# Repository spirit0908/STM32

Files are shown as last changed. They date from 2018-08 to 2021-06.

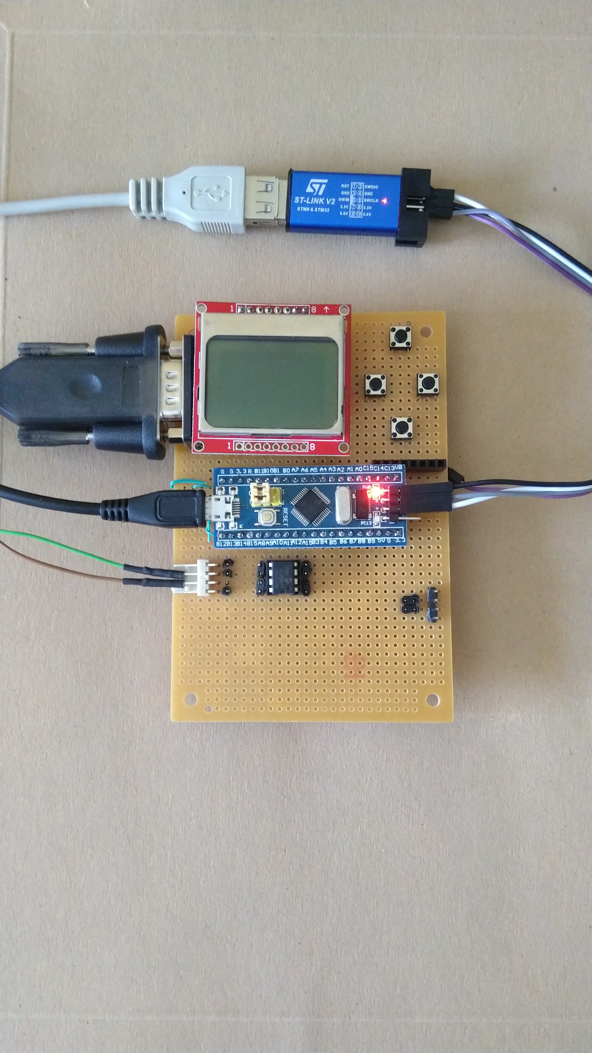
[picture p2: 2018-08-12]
PCB/STM32_proto_board.jpg

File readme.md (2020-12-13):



# Presentation of the project

## Modules
- Light management (dimmer, timer, LED strips...)
- Switch management
- Security Keypad
- Heat management

## Boards
- Development board (Proto board)
- Wall switch board
- Light control board
- Heater control board

## Architecture

Distributed network based on CAN bus

```
                        temp.                   wall
  I/O  I/O              sensor          light  switch
   |    |                 |               |       |
 +-+----+-----+     +-----+------+     +--+-------+-+
 |            |     |            |     |            |
 |  Module 1  |     |  Module 3  |     |  Moduel 5  |
 |            |     |            |     |            |
 +-----+------+     +-----+------+     +-----+------+ 
       |                  |                  |
       +-----+------------+-----+------------+-------- CAN Bus
             |                  |
       +-----+------+     +-----+------+ 
       |            |     |            |
       |  Module 2  |     |  Module 4  |
       |            |     |            |
       +-+-------+--+     +-----+------+
         |       |              |
       RFID   iButton      smart meter
      reader  reader        interface
```

## Boards

### Proto board
- LCD
- 4x switch
- 4x control output (RGBW)
- RS232
- CAN

### Relay board
- 4x switch
- 4x control output (RGBW)
- 6x relay output
- RS232
- CAN

### Intercom board
- 3x sensor input
- 2x relay output
- RS232
- CAN

# How to use

## How to compile

make

## How to execute the tests

make test

Test results location: out/tests/Test_report.html

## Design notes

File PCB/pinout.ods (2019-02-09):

Pin | Name | Port/Pin | Analog | Special function |  | PWM | Board
1 | +3.3V
2 | GND
3 | +5V
4 | PB9 | PB_9 | D14 | CAN1 TD | I2C1 SDA |  |  | PN532_SDA
5 | PB8 | PB_8 | D15 | CAN1 RD | I2C1 SCL |  |  | PN532_SCL
6 | PB7 | PB_7 |  | Serial1 RX | I2C1 SDA |  |  | FREE
7 | PB6 | PB_6 | D10 | Serial1 TX | I2C1 SCL |  |  | FREE
8 | PB5 | PB_5 | D4 | SPI1 MOSI |  | PWM3/2 | CAN_RS
9 | PB4 | PB_4 | D5 | SPI1 MISO |  | PWM3/1 |  | FREE
10 | PB3 | PB_3 | D3 | SPI1 SCK |  | PWM2/2 | LCD_CLK
11 | PA15 | PA_15 |  | SPI1 NSS |  | PWM2/1 |  | FREE
12 | PA12 | PA_12 | USB DP | CAN1 TD |  |  | CAN_TX
13 | PA11 | PA_11 | USB DM | CAN1 RD |  | PWM1/4 | CAN_RX
14 | PA10 | PA_10 | D2 | Serial1 TX |  | PWM1/3 |  | LED_STRIP | TIM3
15 | PA9 | PA_9 | D8 | Serial1 RX |  | PWM1/2 |  | LED_STRIP | TIM3
16 | PA8 | PA_8 | D7 |  |  | PWM1/1 |  | LED_STRIP | TIM3
17 | PB15 | PB_15 |  | SPI2 MOSI |  | PWM1/2N | LCD_DIN
18 | PB14 | PB_14 |  | SPI2 MISO |  | PWM1/2N | LCD_DC
19 | PB13 | PB_13 |  | SPI2 SCK |  | PWM1/1N | LCD_CE
20 | PB12 | PB_12 |  | SPI2 NSS |  |  | LCD_RST
21 | VSS
22 | VSS
23 | +3.3V
24 | RESET
25 | PB11 |  |  | Serial3 RX | I2C2 SDA |  | Teleinfo_EDF
26 | PB10 | PB_10 | D6 | Serial3 TX | I2C2 SCL |  | ND
27 | PB1 | PB_1 |  |  | Analog In |  |  | FREE
28 | PB0 | PB_0 | A3 |  | Analog In | PWM3/3 | LED_STRIP_R
29 | PA7 | PA_7 | D11 | SPI1 MOSI | Analog In | PWM3/2 | LED_STRIP_G
30 | PA6 | PA_6 | D12 | SPI1 MISO | Analog In | PWM3/1 | LED_STRIP_B
31 | PA5 | PA_5 | D13 | SPI1 SCK | Analog In |  |  | Relay2
32 | PA4 | PA_4 | A2 | SPI1 NSS | Analog In |  |  | Relay1
33 | PA3 | PA_3 | D0 | Serial2 RX | Analog In | PWM2/4 | Serial DBG RX
34 | PA2 | PA_2 | D1 | Serial2 TX | Analog In | PWM2/3 | Serial DBG TX
35 | PA1 | PA_1 | A1 |  | Analog In | PWM2/2 | PB_RIGHT
36 | PA0 | PA_0 | A0 |  | Analog In |  | PB_UP
37 | PC15 | PC_15 |  |  |  |  | PB_LEFT
38 | PC14 | PC_14 |  |  |  |  | PB_DOWN
39 | PC13 | PC_13 | C13 |  |  |  | LED
40 | VBAT

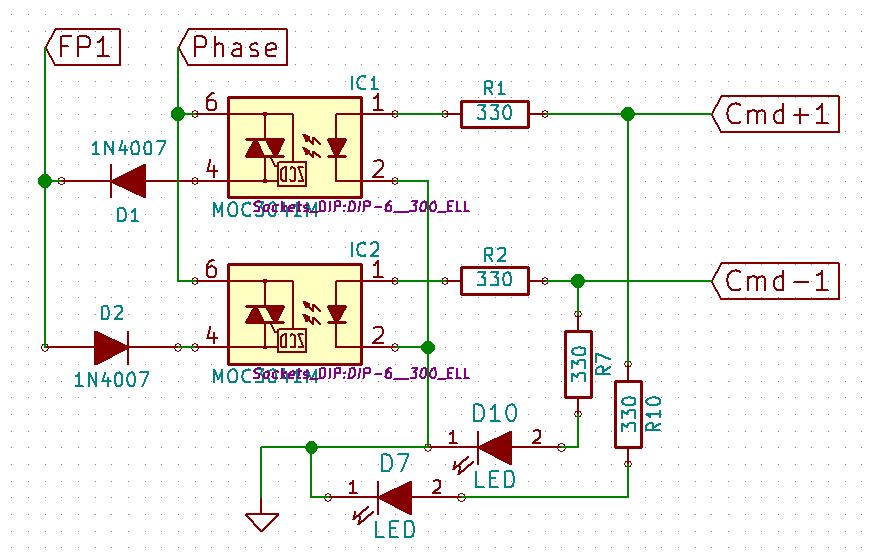
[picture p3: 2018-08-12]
modules/FilPilote/FilPilote_sch.jpg

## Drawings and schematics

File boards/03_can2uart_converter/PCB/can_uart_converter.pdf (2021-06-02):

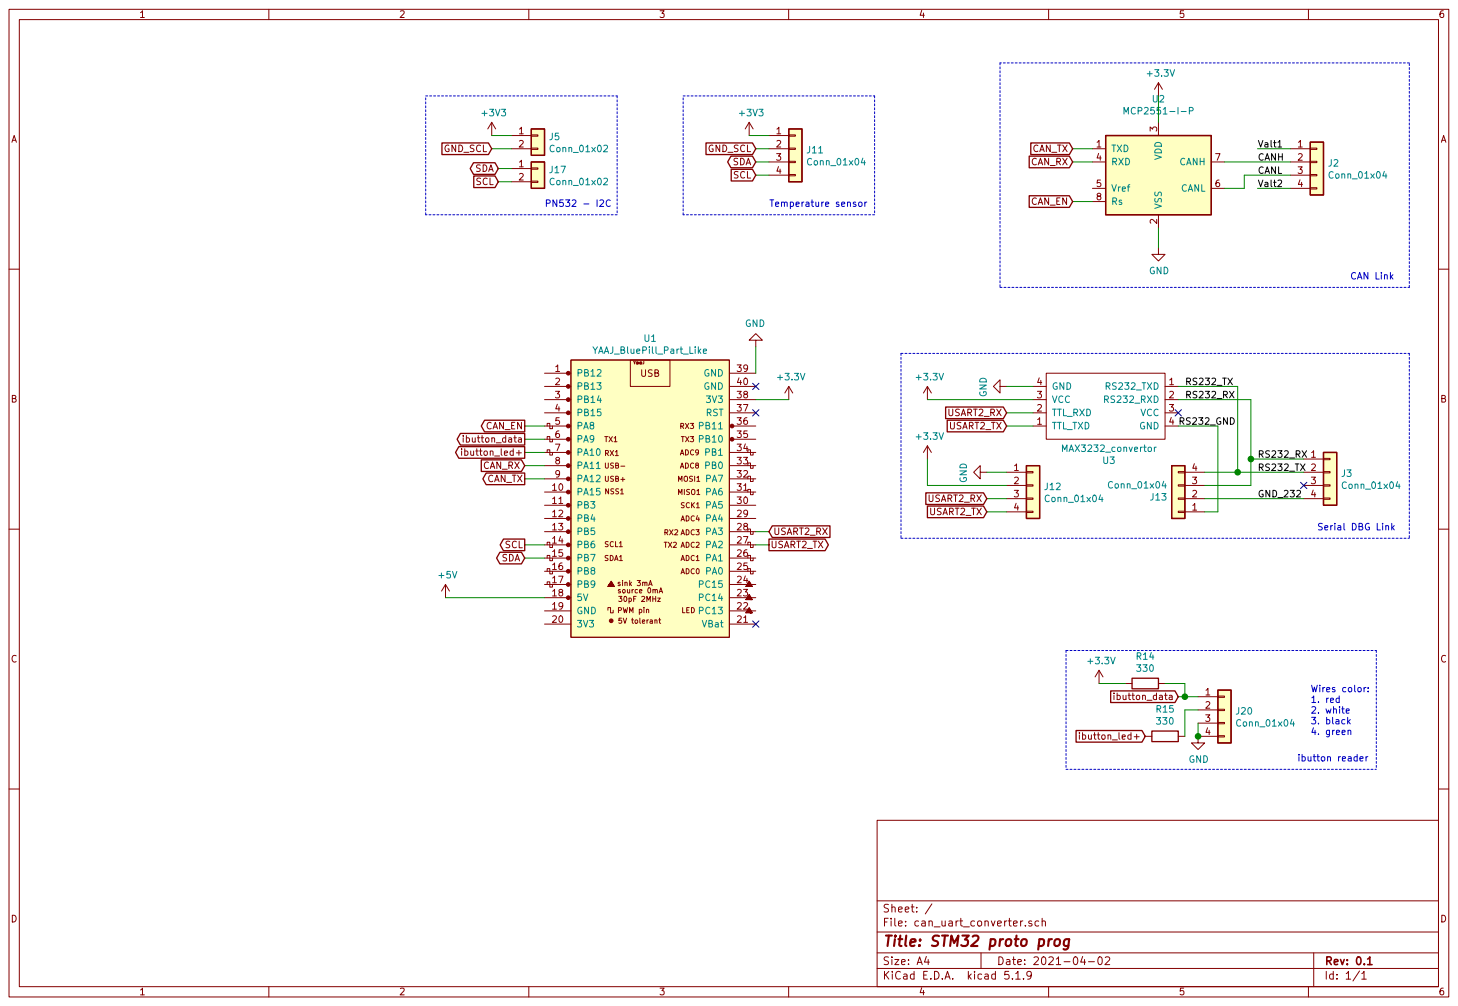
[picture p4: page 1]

3 RXD 4 Vref 5 CANL 6 CANH 7 Rs 8 U2 +3V3 MCP2551-I-P RS232_TXD 1 TTL_TXD 1 RS232_RXD 2 TTL_RXD 2 VCC 3 VCC 3 GND 4 GND 4 U3 MAX3232_convertor 1

File: can_uart_converter.sch Sheet: /
Id: 1/1 Title: STM32 proto prog

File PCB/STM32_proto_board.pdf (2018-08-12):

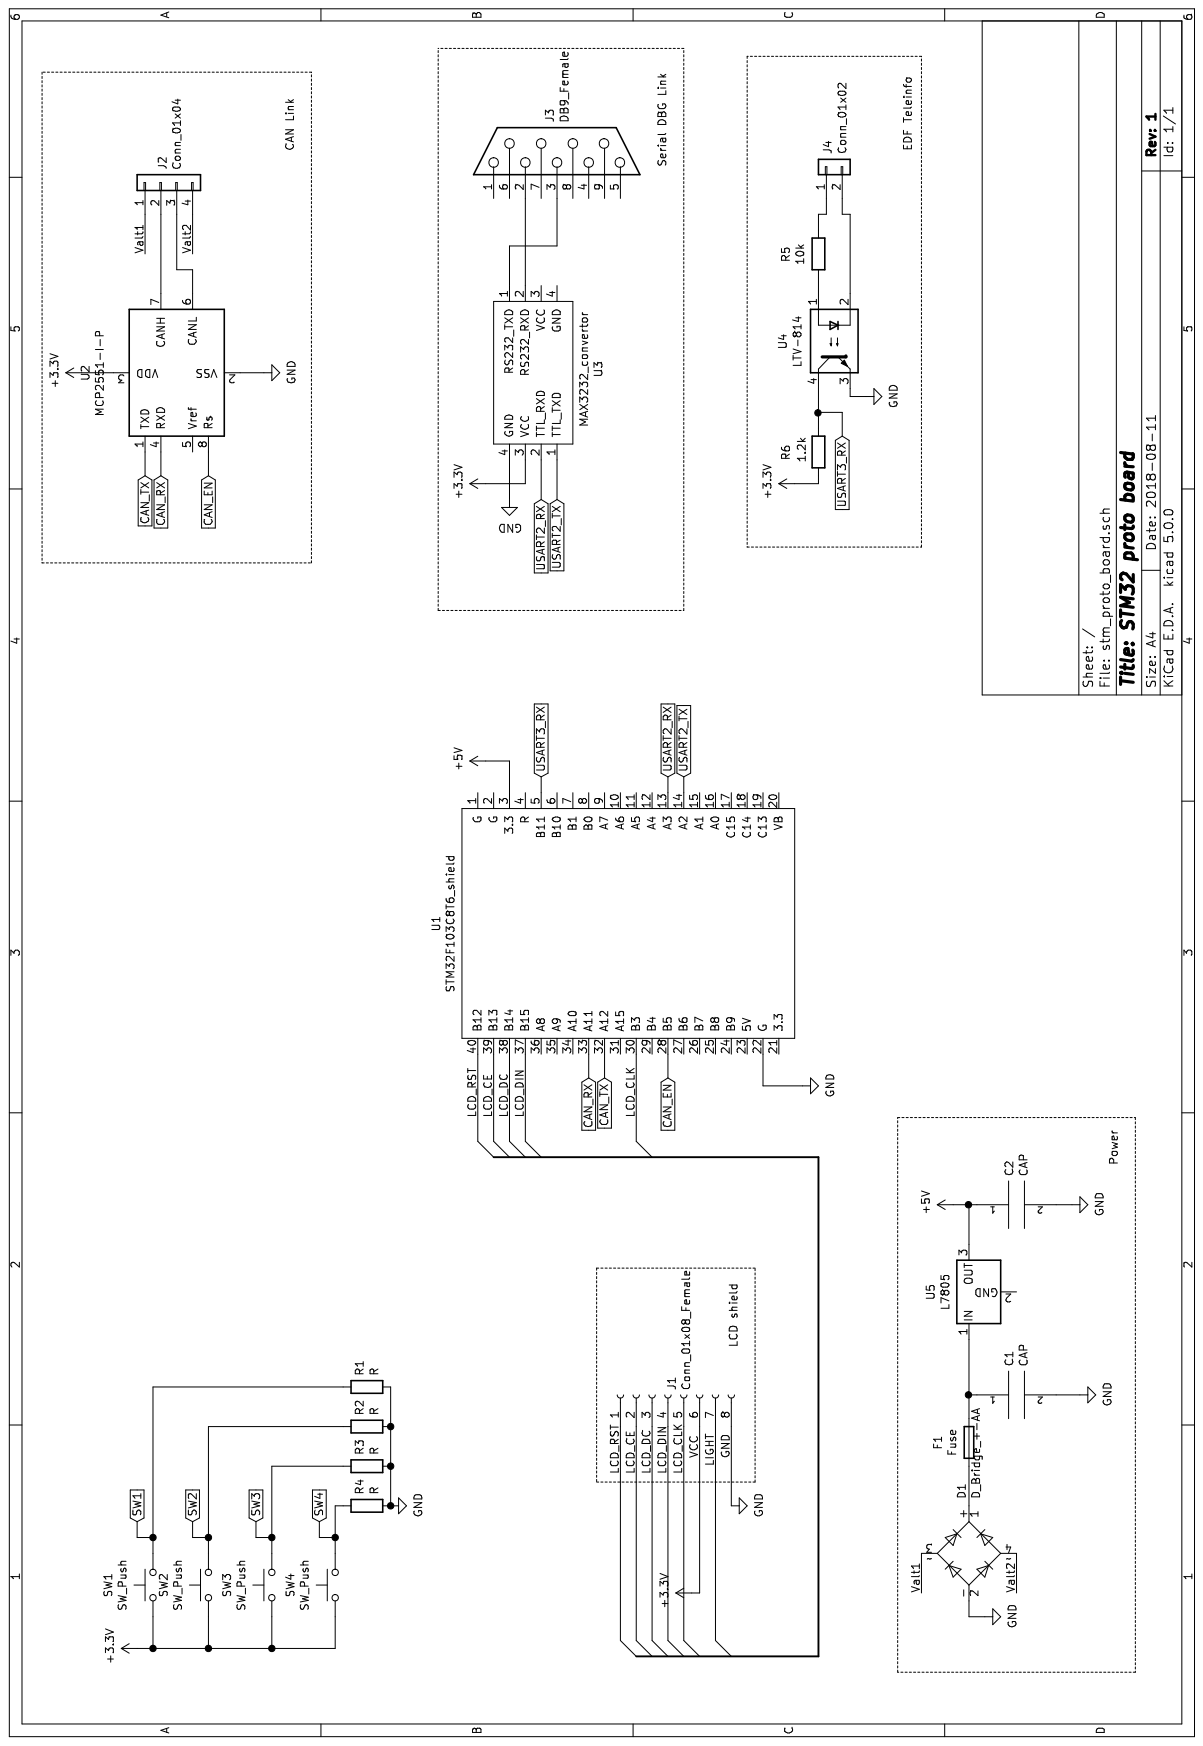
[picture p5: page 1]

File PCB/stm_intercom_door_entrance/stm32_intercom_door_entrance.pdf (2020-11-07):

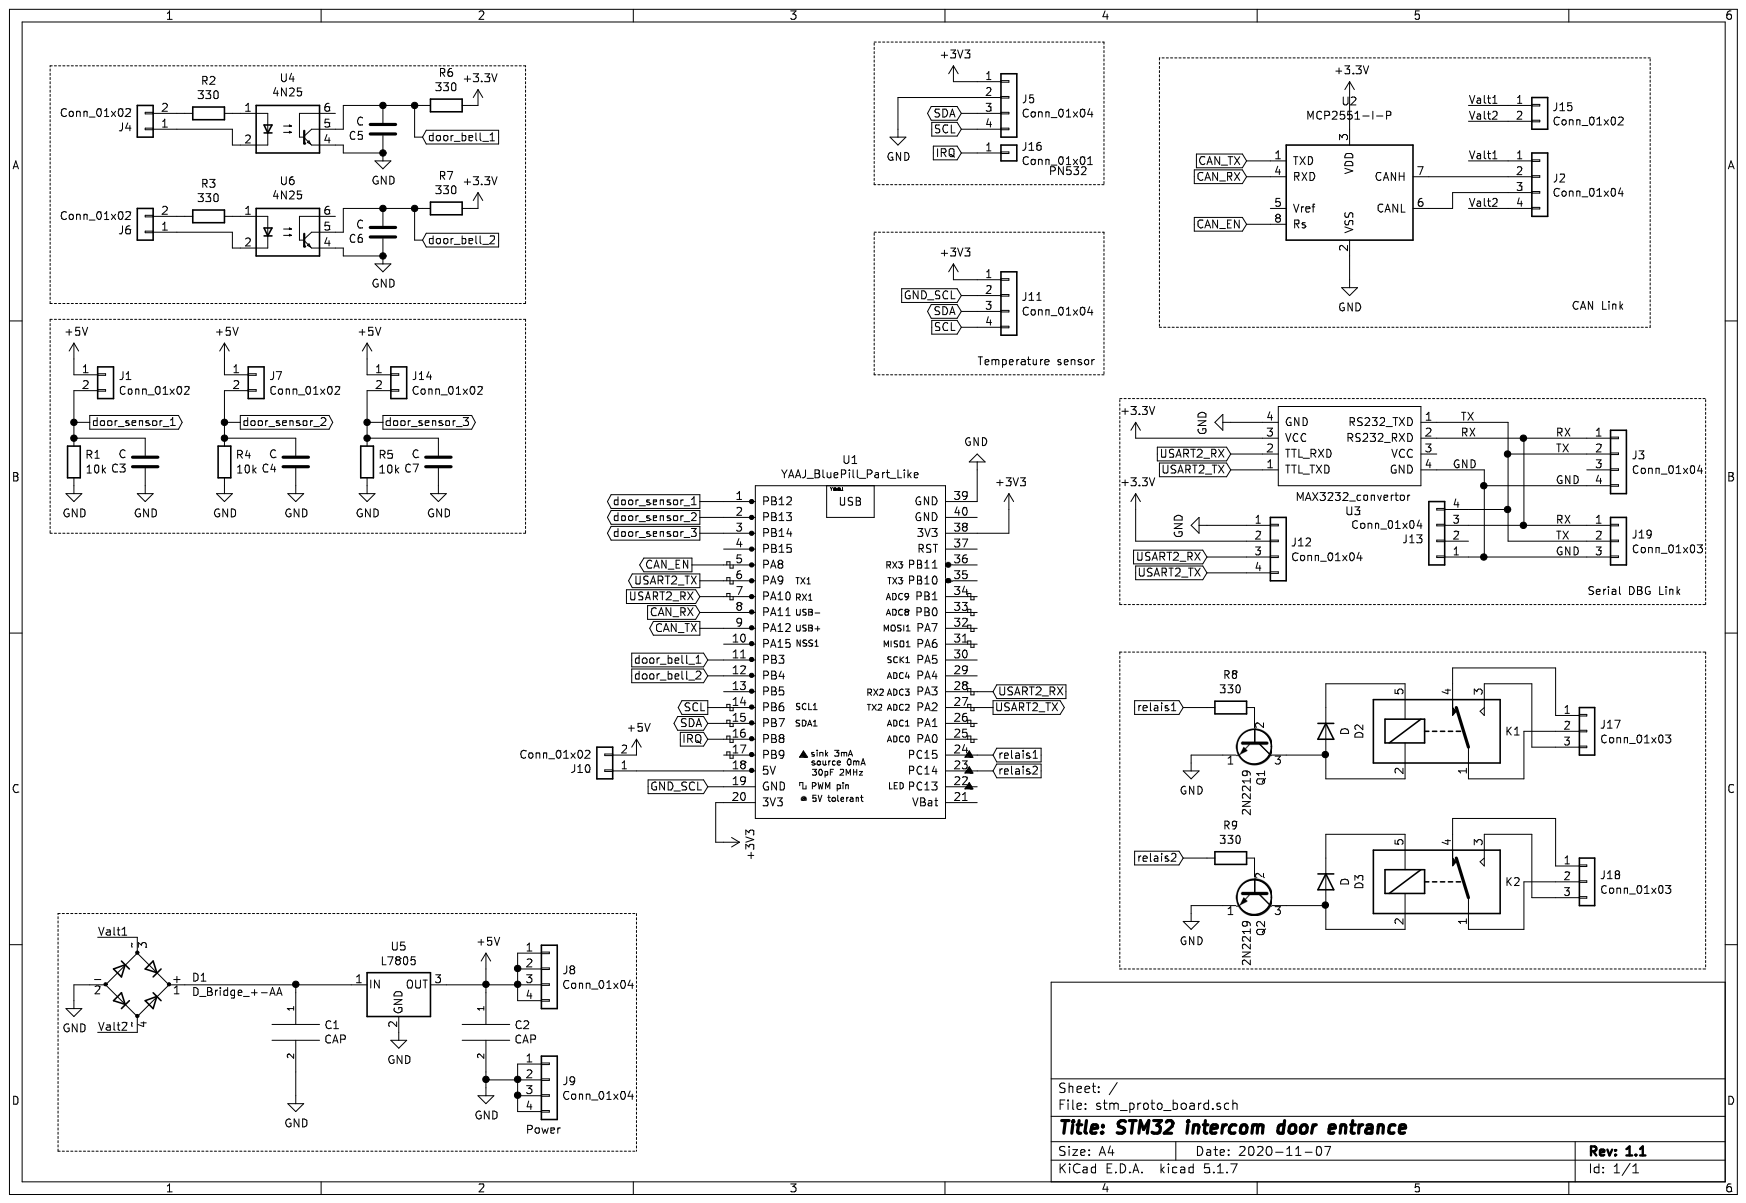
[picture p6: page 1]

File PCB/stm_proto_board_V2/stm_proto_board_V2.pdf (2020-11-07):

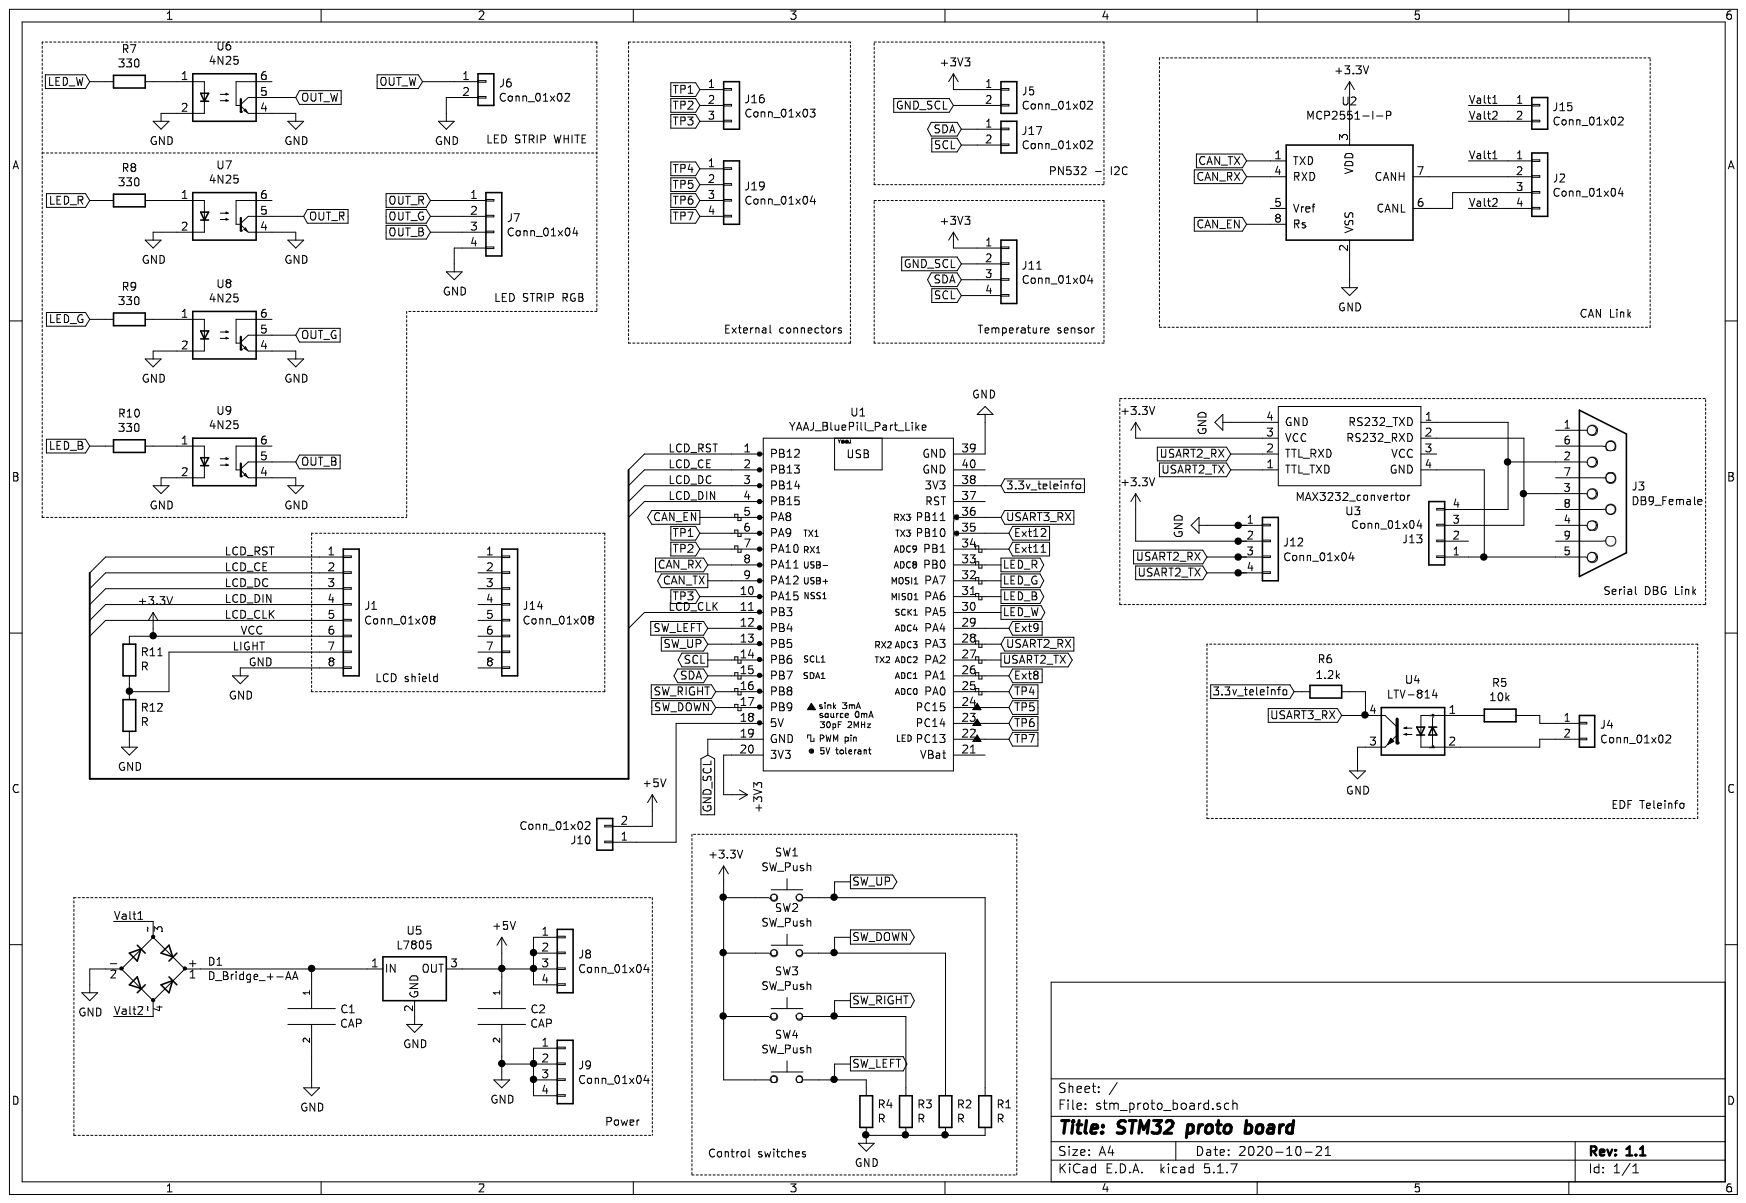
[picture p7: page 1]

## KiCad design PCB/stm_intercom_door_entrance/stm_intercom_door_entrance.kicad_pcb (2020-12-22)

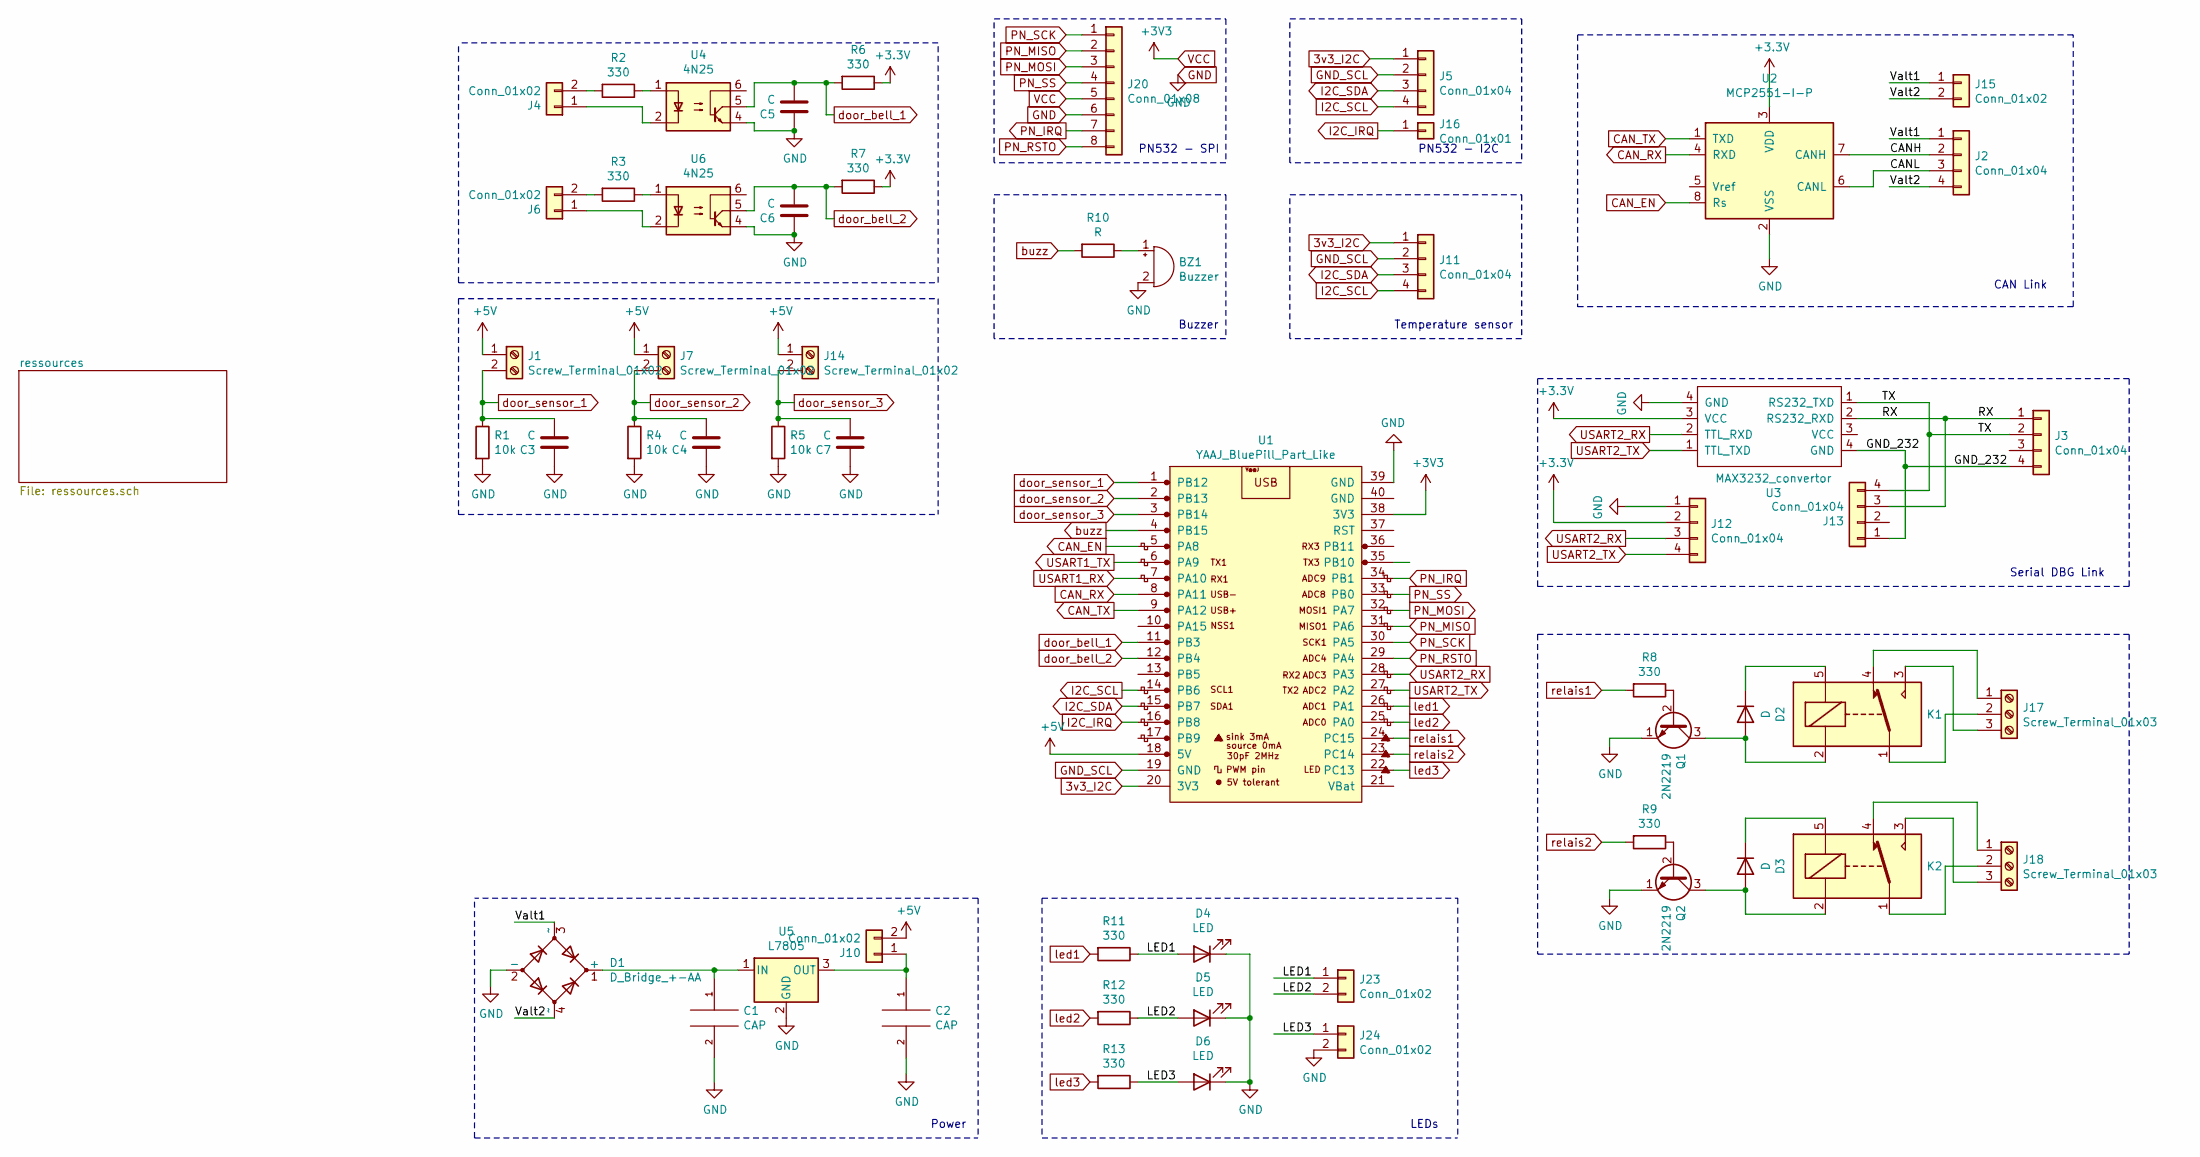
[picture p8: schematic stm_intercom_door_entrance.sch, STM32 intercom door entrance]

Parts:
BZ1: Buzzer; Buzzer_12x9.5RM7.6
C1: CAP; CP_Radial_D6.3mm_P2.50mm
C2: CAP; CP_Radial_D5.0mm_P2.50mm
C3, C4, C7: C; C_Disc_D4.3mm_W1.9mm_P5.00mm
C5, C6: C; CP_Radial_D5.0mm_P2.50mm
D1: D_Bridge_+-AA; Diode_Bridge_DIP-4_W7.62mm_P5.08mm
D2, D3: D; D_5W_P10.16mm_Horizontal
D4, D5, D6: LED
J1, J7, J14: Screw_Terminal_01x02; TerminalBlock_TE_282834-2_1x02_P2.54mm_Horizontal
J2: Conn_01x04; PinHeader_1x04_P2.54mm_Horizontal
J3, J5, J11, J12, J13: Conn_01x04; PinHeader_1x04_P2.54mm_Vertical
J4, J6, J10, J15, J23, J24: Conn_01x02; PinHeader_1x02_P2.54mm_Vertical
J16: Conn_01x01; PinHeader_1x01_P2.54mm_Vertical
J17, J18: Screw_Terminal_01x03; TerminalBlock_TE_282834-3_1x03_P2.54mm_Horizontal
J20: Conn_01x08; PinHeader_1x08_P2.54mm_Vertical
K1, K2: SANYOU_SRD_Form_C; Relay_SPDT_SANYOU_SRD_Series_Form_C
Q1, Q2: 2N2219; TO-39-3
R1, R4, R5: 10k; R_Axial_DIN0207_L6.3mm_D2.5mm_P10.16mm_Horizontal
R2, R3, R6, R7, R8, R9: 330; R_Axial_DIN0204_L3.6mm_D1.6mm_P7.62mm_Horizontal
R10: R; R_Axial_DIN0207_L6.3mm_D2.5mm_P10.16mm_Horizontal
R11, R12, R13: 330; R_Axial_DIN0204_L3.6mm_D1.6mm_P5.08mm_Vertical
U1: YAAJ_BluePill_Part_Like; YAAJ_BluePill_1
U2: MCP2551-I-P; DIP-8_W7.62mm
U3: MAX3232_convertor
U4, U6: 4N25; DIP-6_W7.62mm
U5: L7805; TO-220-3_Vertical

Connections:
3v3_I2C: J5.1, J11.1, U1.20 (3V3)
+5V: J1.1, J7.1, J10.2, J14.1, U1.18 (5V)
/CANH: J2.2, U2.7 (CANH)
/CANL: J2.3, U2.6 (CANL)
/GND_232: J3.4, J13.1, U3.4 (GND)
/LED1: D4.2 (A), J23.1, R11.1
/LED2: D5.2 (A), J23.2, R12.1
/LED3: D6.2 (A), J24.1, R13.1
/RX: J3.1, J13.3, U3.2 (RS232_RXD)
/TX: J3.2, J13.4, U3.1 (RS232_TXD)
/Valt1: D1.3 (~~), J2.1, J15.1
/Valt2: D1.4 (~~), J2.4, J15.2
CAN_EN: U1.5 (PA8), U2.8 (Rs)
CAN_RX: U1.8 (PA11), U2.4 (RXD)
CAN_TX: U1.9 (PA12), U2.1 (TXD)
GND: BZ1.2 (+), C1.2, C2.2, C3.1, C4.1, C5.1, C6.1, C7.1, D1.2 (-), D4.1 (K), D5.1 (K), D6.1 (K), J12.1, J20.6, J24.2, Q1.1 (E), Q2.1 (E), R1.2, R4.2, R5.2, U1.39 (GND), U2.2 (VSS), U3.4 (GND), U4.4, U5.2 (GND), U6.4; also elsewhere on the board
GND_SCL: J5.2, J11.2, U1.19 (GND)
I2C_IRQ: J16.1, U1.16 (PB8)
I2C_SCL: J5.4, J11.4, U1.14 (PB6)
I2C_SDA: J5.3, J11.3, U1.15 (PB7)
LED_iButton: U1.7 (PA10); also elsewhere on the board
unnamed: BZ1.1 (-), R10.1
unnamed: C1.1, D1.1 (+), U5.1 (IN)
unnamed: C2.1, J10.1, U5.3 (OUT)
unnamed: D2.1 (K), K1.5
unnamed: D2.2 (A), K1.2, Q1.3 (C)
unnamed: D3.1 (K), K2.5
unnamed: D3.2 (A), K2.2, Q2.3 (C)
unnamed: J4.1, U4.2
unnamed: J4.2, R2.2
unnamed: J6.1, U6.2
unnamed: J6.2, R3.2
unnamed: J17.1, K1.4
unnamed: J17.2, K1.1
unnamed: J17.3, K1.3
unnamed: J18.1, K2.4
unnamed: J18.2, K2.1
unnamed: J18.3, K2.3
unnamed: Q1.2 (B), R8.1
unnamed: Q2.2 (B), R9.1
unnamed: R2.1, U4.1
unnamed: R3.1, U6.1
PN_IRQ: J20.7, U1.34 (PB1)
PN_MISO: J20.2, U1.31 (PA6)
PN_MOSI: J20.3, U1.32 (PA7)
PN_RSTO: J20.8, U1.29 (PA4)
PN_SCK: J20.1, U1.30 (PA5)
PN_SS: J20.4, U1.33 (PB0)
USART2_RX: J12.3, U1.28 (PA3), U3.2 (RS232_RXD)
USART2_TX: J12.4, U1.27 (PA2), U3.1 (RS232_TXD)
buzz: R10.2, U1.4 (PB15)
door_bell_1: C5.2, R6.2, U1.11 (PB3), U4.5
door_bell_2: C6.2, R7.2, U1.12 (PB4), U6.5
door_sensor_1: C3.2, J1.2, R1.1, U1.1 (PB12)
door_sensor_2: C4.2, J7.2, R4.1, U1.2 (PB13)
door_sensor_3: C7.2, J14.2, R5.1, U1.3 (PB14)
iButton_Data: U1.6 (PA9); also elsewhere on the board
led1: R11.2, U1.26 (PA1)
led2: R12.2, U1.25 (PA0)
led3: R13.2, U1.22 (PC13)
relais1: R8.2, U1.24 (PC15)
relais2: R9.2, U1.23 (PC14)

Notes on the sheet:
Serial DBG Link
CAN Link
PN532 - I2C
Temperature sensor
Power
PN532 - SPI
Buzzer
LEDs

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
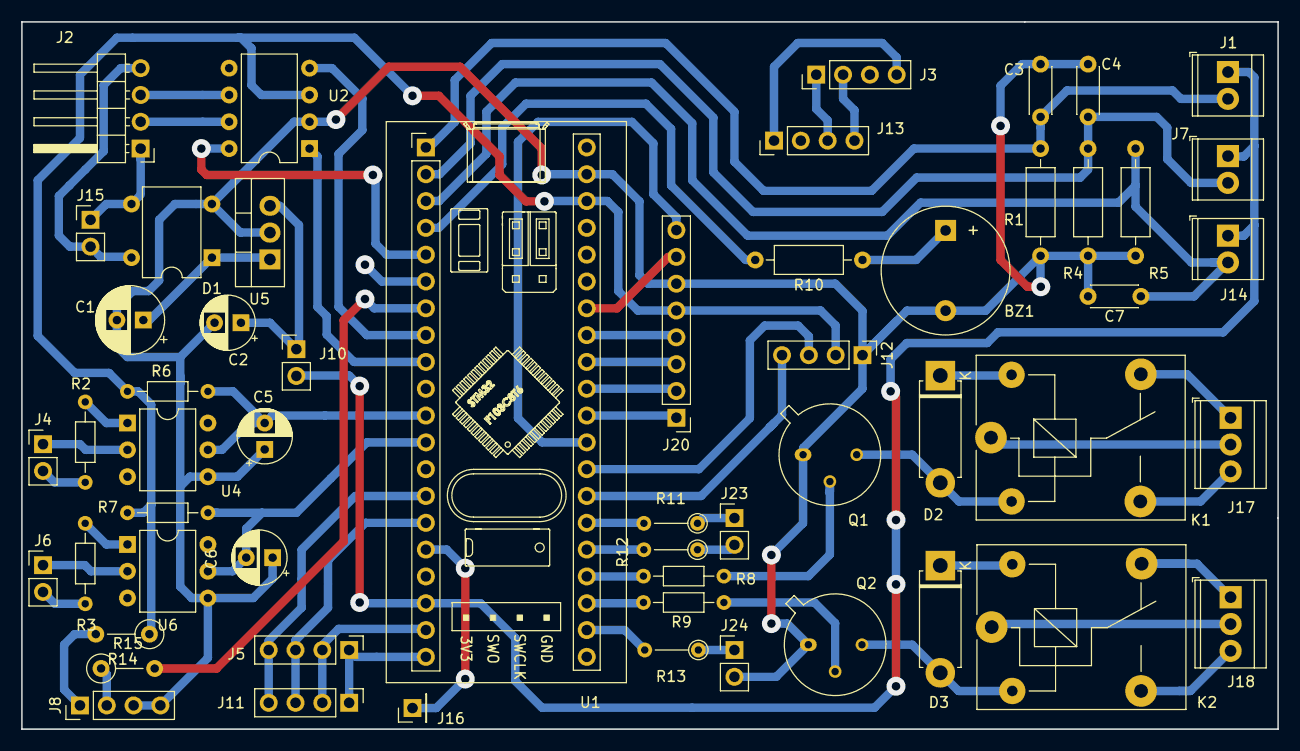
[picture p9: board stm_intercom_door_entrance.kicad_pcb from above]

Board: 2 copper layers, 119.0 x 67.0 mm, 55 parts (0 on the bottom side), 64 nets.

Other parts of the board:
J8: Conn_01x04; PinHeader_1x04_P2.54mm_Vertical
R14, R15: 10k; R_Axial_DIN0207_L6.3mm_D2.5mm_P5.08mm_Vertical

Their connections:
GND: J8.3, J8.4; also elsewhere on the board
LED_iButton: R15.2; also elsewhere on the board
unnamed: J8.2, R15.1
iButton_Data: J8.1, R14.2; also elsewhere on the board

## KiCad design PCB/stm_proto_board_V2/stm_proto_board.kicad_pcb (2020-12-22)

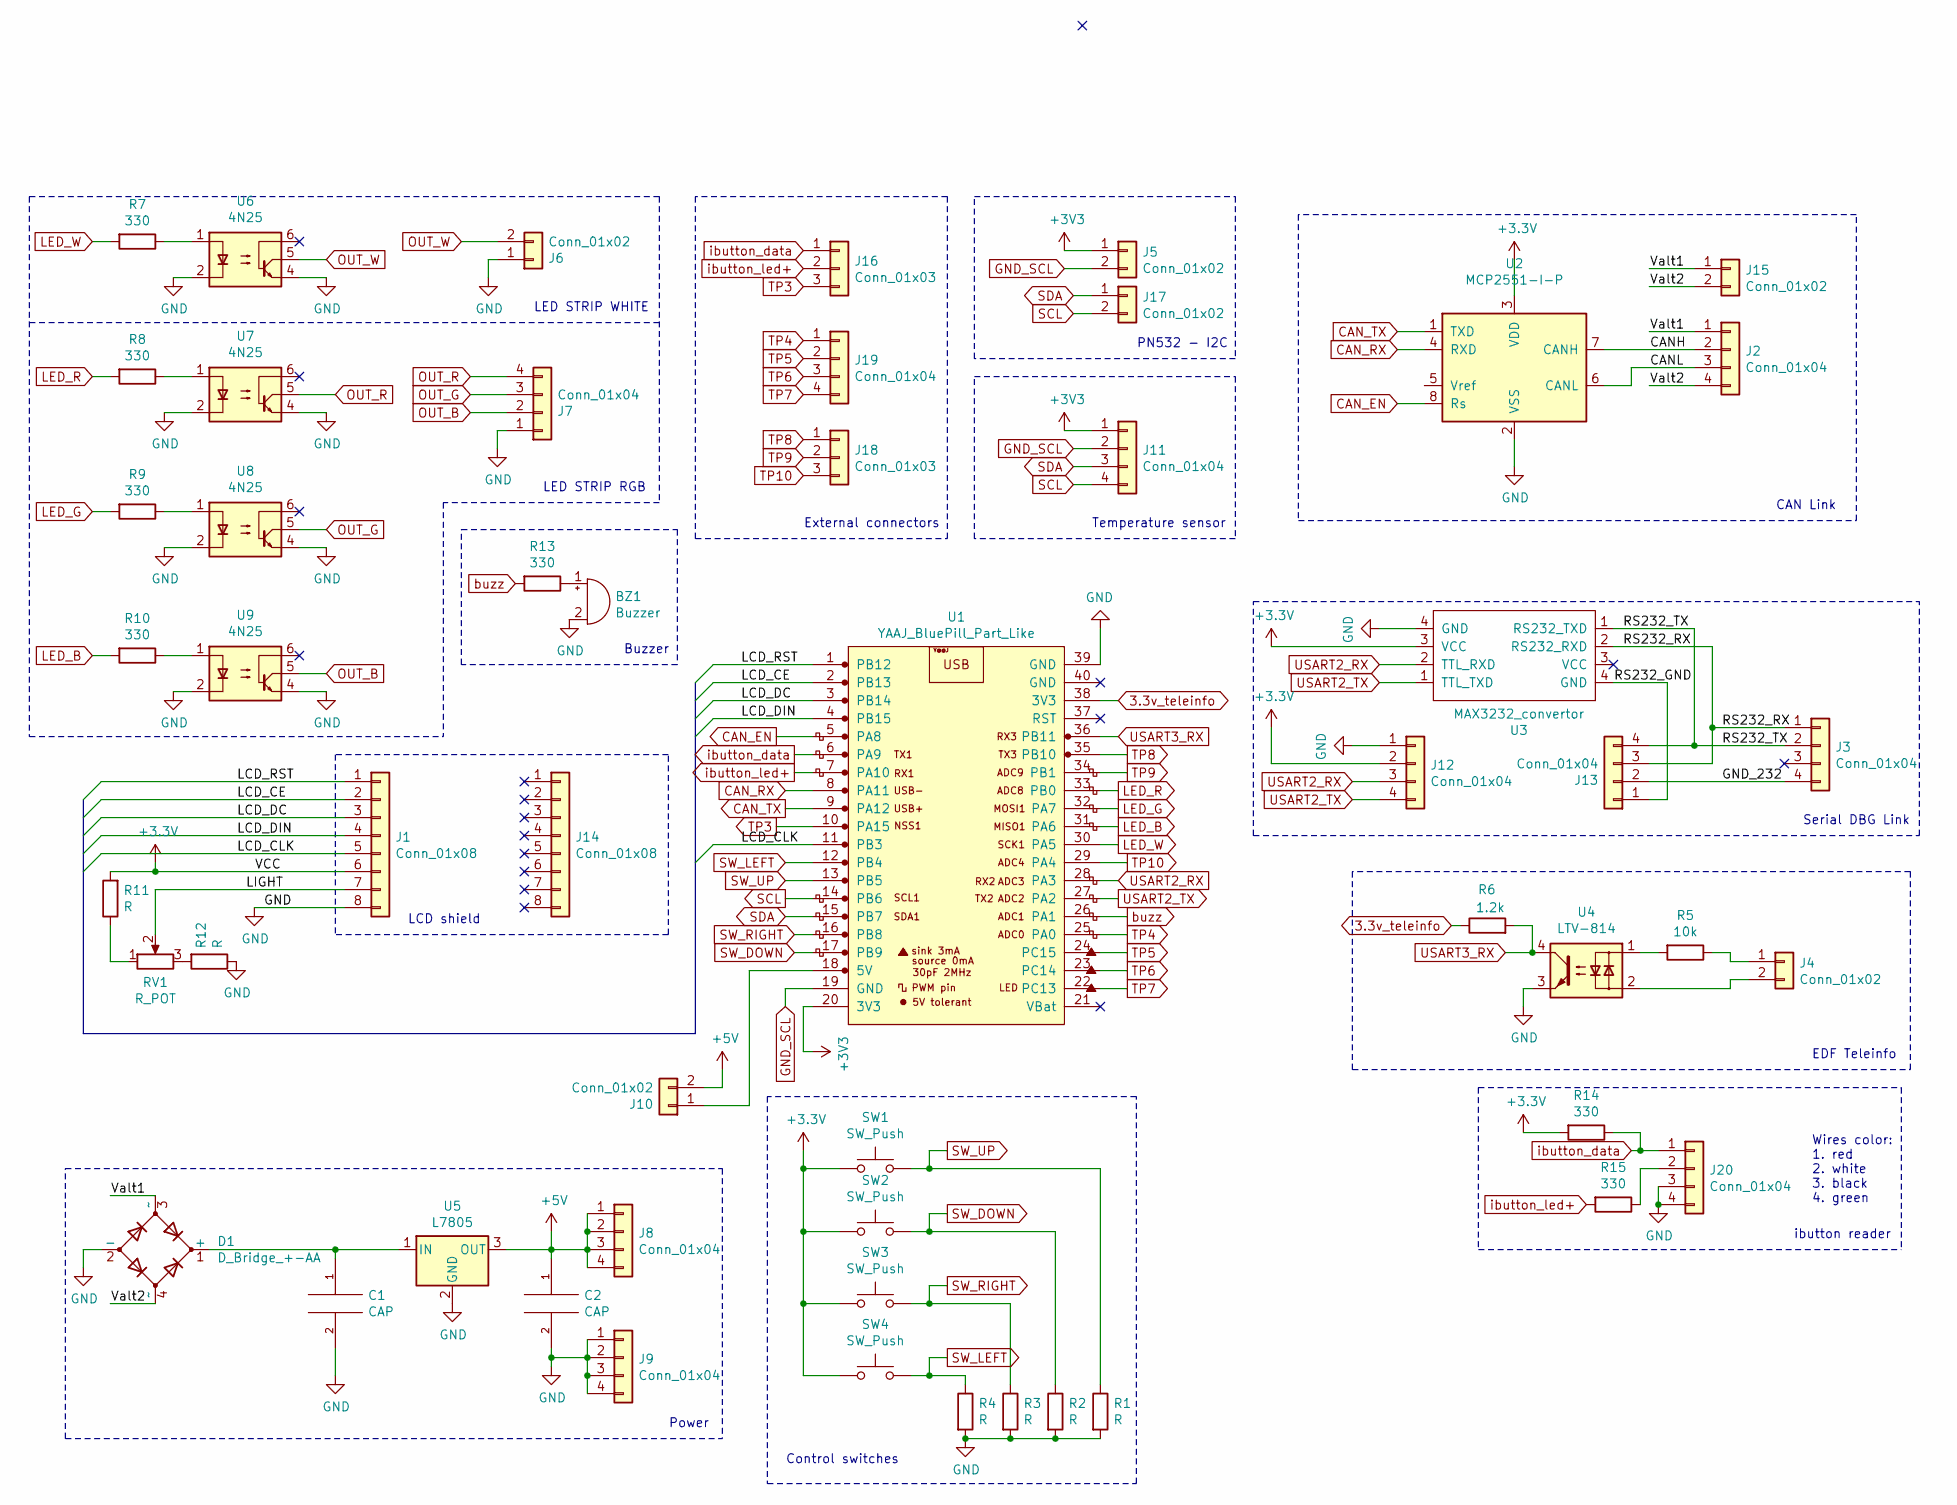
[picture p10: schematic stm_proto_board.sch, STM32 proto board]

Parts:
BZ1: Buzzer; Buzzer_12x9.5RM7.6
C1: CAP; CP_Radial_D6.3mm_P2.50mm
C2: CAP; CP_Radial_D5.0mm_P2.50mm
D1: D_Bridge_+-AA; Diode_Bridge_DIP-4_W7.62mm_P5.08mm
J1, J14: Conn_01x08; PinHeader_1x08_P2.54mm_Vertical
J2: Conn_01x04; PinHeader_1x04_P2.54mm_Horizontal
J3, J7, J8, J9, J11, J12, J13, J19, J20: Conn_01x04; PinHeader_1x04_P2.54mm_Vertical
J4, J5, J6, J10, J15, J17: Conn_01x02; PinHeader_1x02_P2.54mm_Vertical
J16, J18: Conn_01x03; PinHeader_1x03_P2.54mm_Vertical
R1, R2, R3: R; R_Axial_DIN0207_L6.3mm_D2.5mm_P15.24mm_Horizontal
R4, R11, R12: R; R_Axial_DIN0207_L6.3mm_D2.5mm_P10.16mm_Horizontal
R5: 10k; R_Axial_DIN0204_L3.6mm_D1.6mm_P5.08mm_Horizontal
R6: 1.2k; R_Axial_DIN0204_L3.6mm_D1.6mm_P7.62mm_Horizontal
R7, R8, R9, R10, R13, R14, R15: 330; R_Axial_DIN0204_L3.6mm_D1.6mm_P7.62mm_Horizontal
RV1: R_POT; Potentiometer_Bourns_3266Z_Horizontal
SW1, SW2, SW3, SW4: SW_Push; SW_PUSH_6mm
U1: YAAJ_BluePill_Part_Like; YAAJ_BluePill_1
U2: MCP2551-I-P; DIP-8_W7.62mm
U3: MAX3232_convertor
U4: LTV-814; DIP-4_W7.62mm
U5: L7805; TO-220-3_Horizontal_TabUp
U6, U7, U8, U9: 4N25; DIP-6_W7.62mm

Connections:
3.3v_teleinfo: R6.1, U1.38 (3V3)
+5V: C2.1, J8.1, J8.2, J8.3, J8.4, J10.2, U5.3 (OUT)
/CANH: J2.2, U2.7 (CANH)
/CANL: J2.3, U2.6 (CANL)
/GND_232: J3.4, J13.2
/LCD_CE: J1.2, U1.2 (PB13)
/LCD_CLK: J1.5, U1.11 (PB3)
/LCD_DC: J1.3, U1.3 (PB14)
/LCD_DIN: J1.4, U1.4 (PB15)
/LCD_RST: J1.1, U1.1 (PB12)
/LIGHT: J1.7, RV1.2
/RS232_GND: J13.1, U3.4 (GND)
/RS232_RX: J3.1, J13.3, U3.2 (RS232_RXD)
/RS232_TX: J3.2, J13.4, U3.1 (RS232_TXD)
/Valt1: D1.3 (~~), J2.1, J15.1
/Valt2: D1.4 (~~), J2.4, J15.2
CAN_EN: U1.5 (PA8), U2.8 (Rs)
CAN_RX: U1.8 (PA11), U2.4 (RXD)
CAN_TX: U1.9 (PA12), U2.1 (TXD)
GND: BZ1.2 (+), C1.2, C2.2, D1.2 (-), J1.8, J6.1, J7.1, J9.1, J9.2, J9.3, J9.4, J12.1, J20.3, J20.4, R1.2, R2.2, R3.2, R4.2, R12.1, U1.39 (GND), U2.2 (VSS), U3.4 (GND), U4.3, U5.2 (GND), U6.2, U6.4, U7.2, U7.4, U8.2, U8.4, U9.2, U9.4
GND_SCL: J5.2, J11.2, U1.19 (GND)
LED_B: R10.2, U1.31 (PA6)
LED_G: R9.2, U1.32 (PA7)
LED_R: R8.2, U1.33 (PB0)
LED_W: R7.2, U1.30 (PA5)
unnamed: BZ1.1 (-), R13.1
unnamed: C1.1, D1.1 (+), U5.1 (IN)
unnamed: J4.1, R5.1
unnamed: J4.2, U4.2
unnamed: J10.1, U1.18 (5V)
unnamed: J20.2, R15.1
unnamed: R5.2, U4.1
unnamed: R7.1, U6.1
unnamed: R8.1, U7.1
unnamed: R9.1, U8.1
unnamed: R10.1, U9.1
unnamed: R11.1, RV1.1
unnamed: R12.2, RV1.3
OUT_B: J7.2, U9.5
OUT_G: J7.3, U8.5
OUT_R: J7.4, U7.5
OUT_W: J6.2, U6.5
SCL: J11.4, J17.2, U1.14 (PB6)
SDA: J11.3, J17.1, U1.15 (PB7)
SW_DOWN: R2.1, SW2.2, U1.17 (PB9)
SW_LEFT: R4.1, SW4.2, U1.12 (PB4)
SW_RIGHT: R3.1, SW3.2, U1.16 (PB8)
SW_UP: R1.1, SW1.2, U1.13 (PB5)
TP3: J16.3, U1.10 (PA15)
TP4: J19.1, U1.25 (PA0)
TP5: J19.2, U1.24 (PC15)
TP6: J19.3, U1.23 (PC14)
TP7: J19.4, U1.22 (PC13)
TP8: J18.1, U1.35 (PB10)
TP9: J18.2, U1.34 (PB1)
TP10: J18.3, U1.29 (PA4)
USART2_RX: J12.3, U1.28 (PA3), U3.2 (RS232_RXD)
USART2_TX: J12.4, U1.27 (PA2), U3.1 (RS232_TXD)
USART3_RX: R6.2, U1.36 (PB11), U4.4
buzz: R13.2, U1.26 (PA1)
ibutton_data: J16.1, J20.1, R14.1, U1.6 (PA9)
ibutton_led+: J16.2, R15.2, U1.7 (PA10)

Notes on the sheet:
Serial DBG Link
EDF Teleinfo
CAN Link
LCD shield
PN532 - I2C
LED STRIP WHITE
Power
Control switches
Buzzer
External connectors
Temperature sensor
LED STRIP RGB
ibutton reader
Wires color: 1. red 2. white 3. black 4. green

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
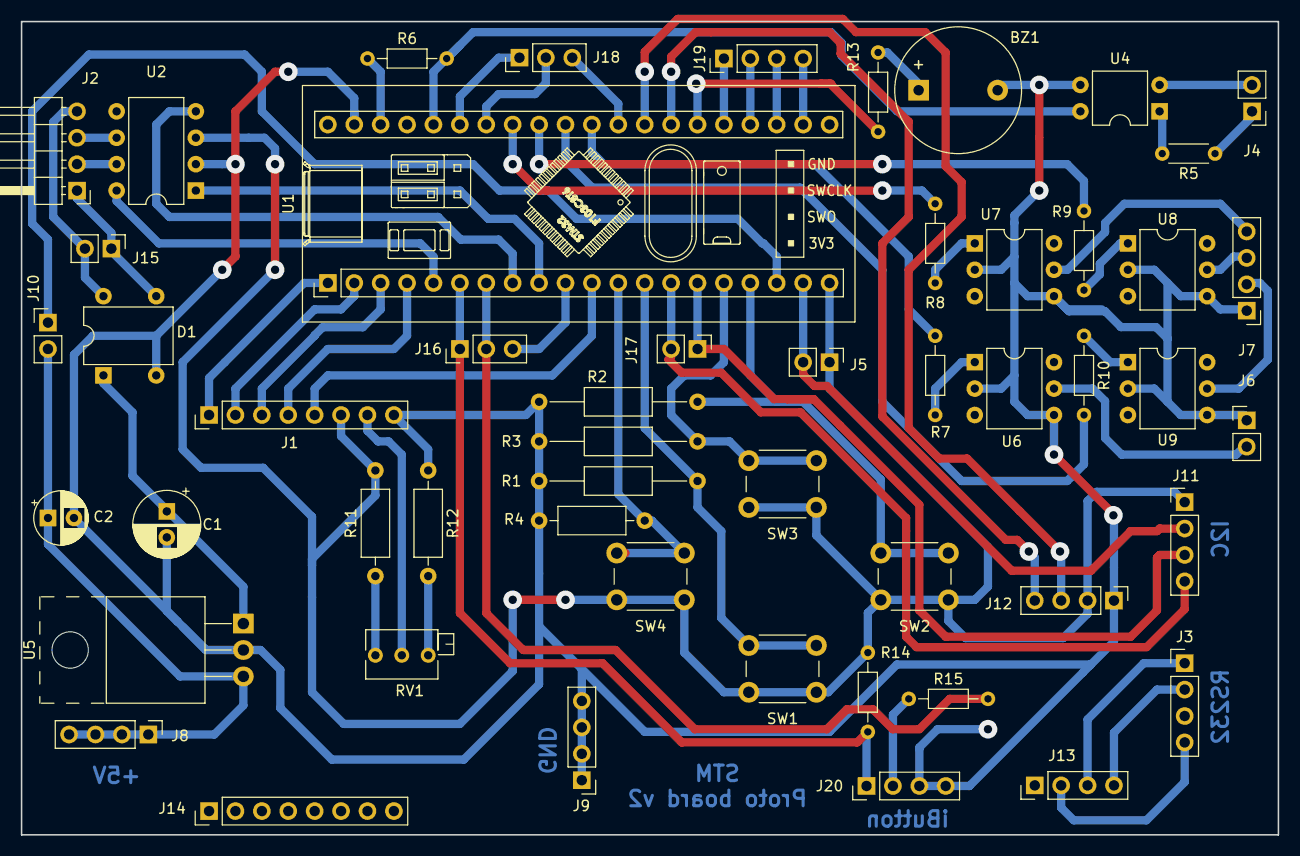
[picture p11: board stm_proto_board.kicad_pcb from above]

Board: 2 copper layers, 120.9 x 78.2 mm, 52 parts (0 on the bottom side), 62 nets.

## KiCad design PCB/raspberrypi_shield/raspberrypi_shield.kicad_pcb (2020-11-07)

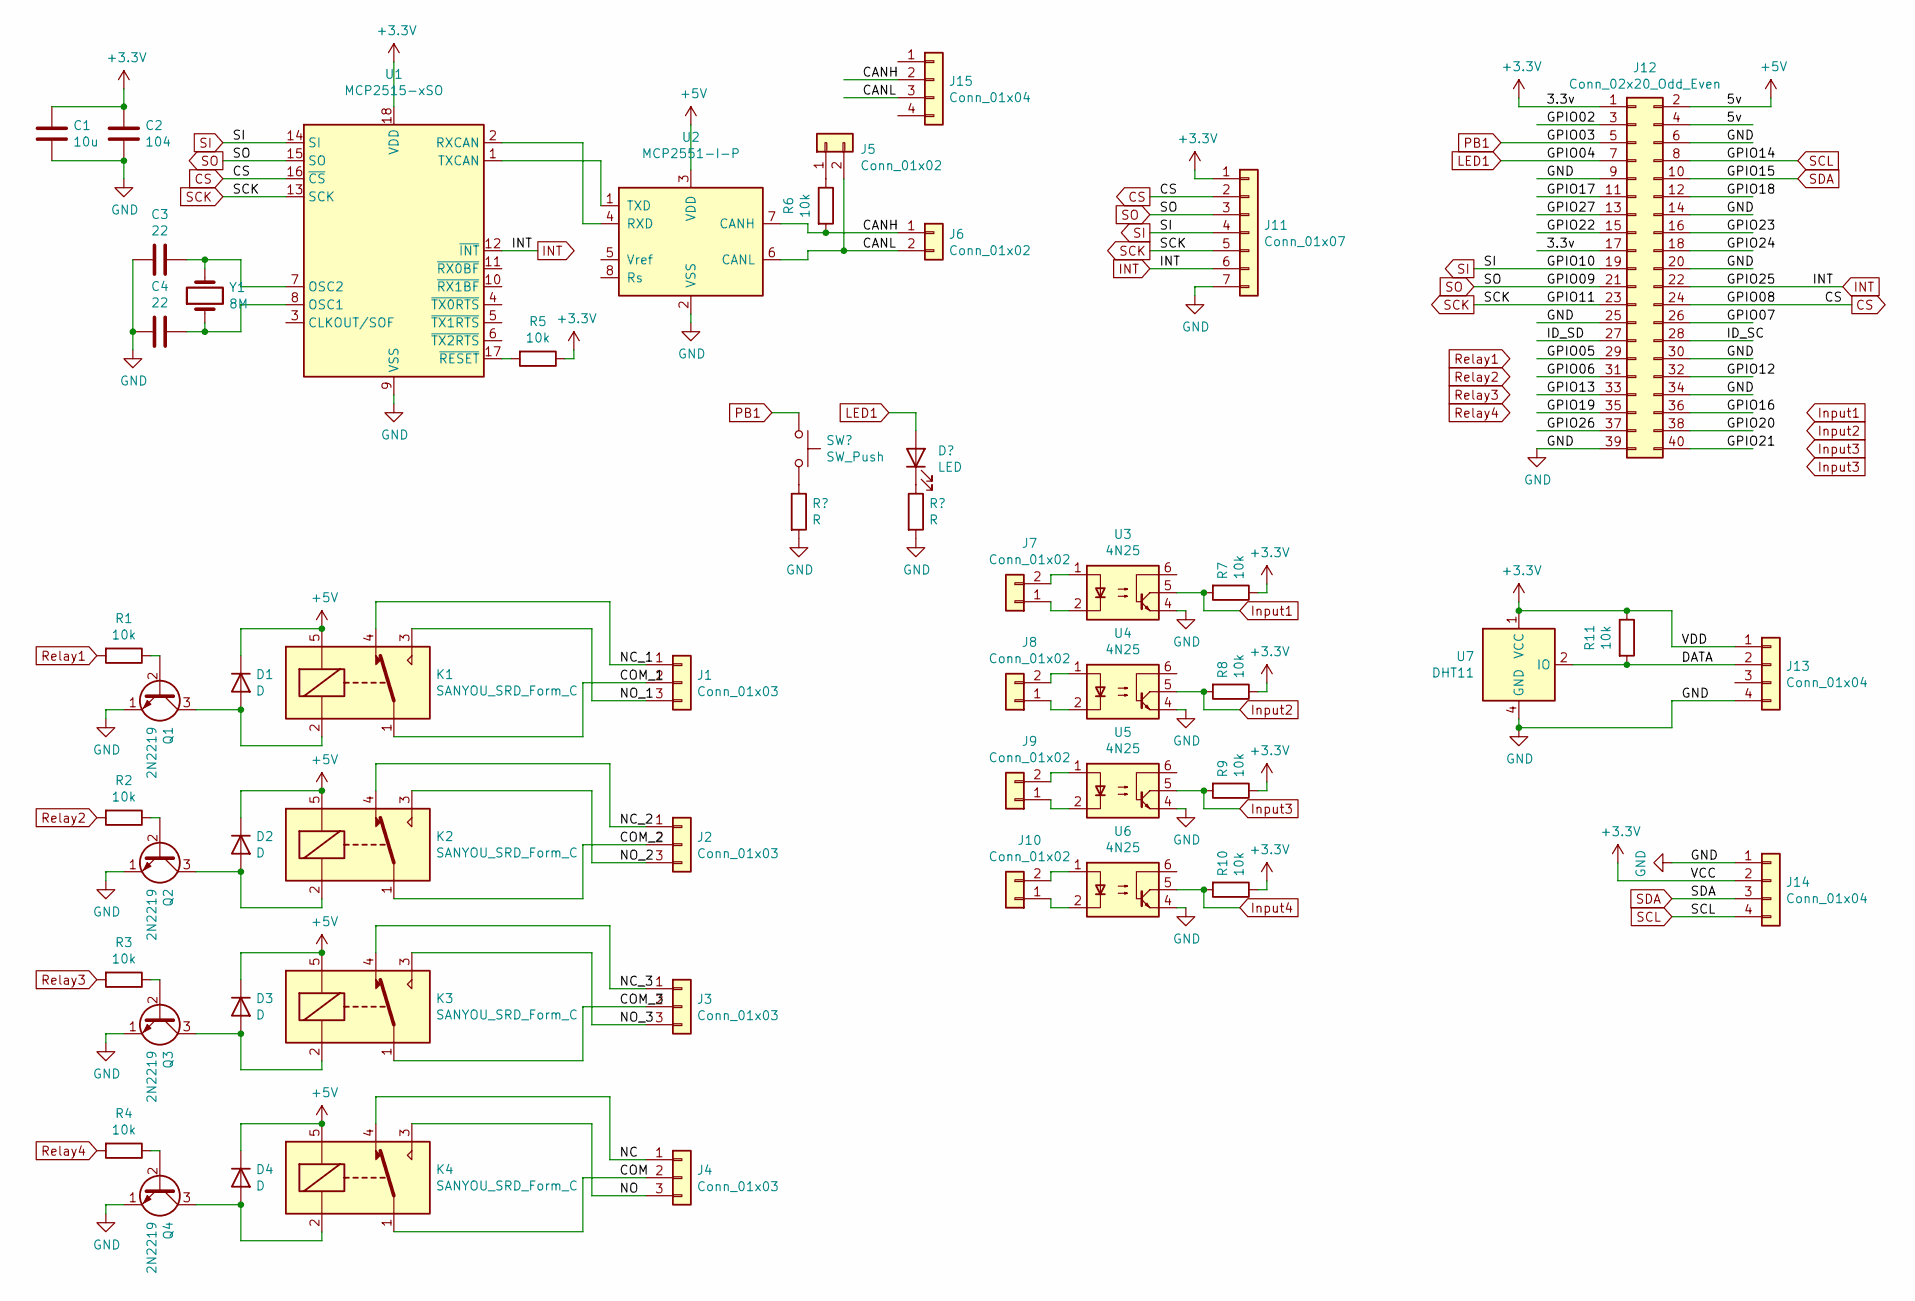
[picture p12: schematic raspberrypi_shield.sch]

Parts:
C1: 10u; C_Disc_D3.0mm_W1.6mm_P2.50mm
C2: 104; C_Disc_D3.0mm_W1.6mm_P2.50mm
C3, C4: 22; C_Disc_D3.0mm_W1.6mm_P2.50mm
D1, D2, D3, D4: D; D_A-405_P7.62mm_Horizontal
J1, J2, J3, J4: Conn_01x03; PinHeader_1x03_P2.54mm_Vertical
J5, J6, J7, J8, J9, J10: Conn_01x02; PinHeader_1x02_P2.54mm_Vertical
J11: Conn_01x07; PinHeader_1x07_P2.54mm_Vertical
J12: Conn_02x20_Odd_Even; PinHeader_2x20_P2.54mm_Vertical
J13, J14, J15: Conn_01x04; PinHeader_1x04_P2.54mm_Vertical
K1, K2, K3, K4: SANYOU_SRD_Form_C; Relay_SPDT_SANYOU_SRD_Series_Form_C
Q1, Q2, Q3, Q4: 2N2219; TO-39-3
R1, R2, R3, R4, R5, R6, R7, R8, R9, R10, R11: 10k; R_Axial_DIN0204_L3.6mm_D1.6mm_P5.08mm_Horizontal
U1: MCP2515-xSO; SOIC-18W_7.5x11.6mm_P1.27mm
U2: MCP2551-I-P; HTSOP-8-1EP_3.9x4.9mm_P1.27mm_EP2.4x3.2mm_ThermalVias
U3, U4, U5, U6: 4N25; DIP-6_W7.62mm
U7: DHT11; Aosong_DHT11_5.5x12.0_P2.54mm
Y1: 8M; R_Axial_DIN0411_L9.9mm_D3.6mm_P7.62mm_Vertical

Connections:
+3V3: C1.2, C2.2, J11.1, J12.1, J12.17, J13.1, J14.2, R5.1, R7.1, R8.1, R9.1, R10.1, R11.1, U1.18 (VDD), U7.1 (VCC)
+5V: D1.1 (K), D2.1 (K), D3.1 (K), D4.1 (K), J12.2, J12.4, K1.5, K2.5, K3.5, K4.5, U2.3 (VDD)
/CANH: J6.1, J15.2, R6.2, U2.7 (CANH)
/CANL: J5.2, J6.2, J15.3, U2.6 (CANL)
/COM: J4.2, K4.1
/COM_1: J1.2, K1.1
/COM_2: J2.2, K2.1
/COM_3: J3.2, K3.1
/DATA: J13.2, R11.2, U7.2 (IO)
/GPIO02: J12.3
/GPIO03: J12.5
/GPIO04: J12.7
/GPIO05: J12.29
/GPIO06: J12.31
/GPIO07: J12.26
/GPIO12: J12.32
/GPIO13: J12.33
/GPIO16: J12.36
/GPIO17: J12.11
/GPIO18: J12.12
/GPIO19: J12.35
/GPIO20: J12.38
/GPIO21: J12.40
/GPIO22: J12.15
/GPIO23: J12.16
/GPIO24: J12.18
/GPIO26: J12.37
/GPIO27: J12.13
/ID_SC: J12.28
/ID_SD: J12.27
/NC: J4.1, K4.4
/NC_1: J1.1, K1.4
/NC_2: J2.1, K2.4
/NC_3: J3.1, K3.4
/NO: J4.3, K4.3
/NO_1: J1.3, K1.3
/NO_2: J2.3, K2.3
/NO_3: J3.3, K3.3
CS: J11.2, J12.24, U1.16 (~CS)
GND: C1.1, C2.1, C3.1, C4.1, J11.7, J12.6, J12.9, J12.14, J12.20, J12.25, J12.30, J12.34, J12.39, J13.4, J14.1, Q1.1 (E), Q2.1 (E), Q3.1 (E), Q4.1 (E), U1.9 (VSS), U2.2 (VSS), U3.4, U4.4, U5.4, U6.4, U7.4 (GND)
INT: J11.6, J12.22, U1.12 (~INT)
Input1: R7.2, U3.5
Input2: R8.2, U4.5
Input3: R9.2, U5.5
Input4: R10.2, U6.5
unnamed: C3.2, U1.7 (OSC2), Y1.2
unnamed: C4.2, U1.8 (OSC1), Y1.1
unnamed: D1.2 (A), K1.2, Q1.3 (C)
unnamed: D2.2 (A), K2.2, Q2.3 (C)
unnamed: D3.2 (A), K3.2, Q3.3 (C)
unnamed: D4.2 (A), K4.2, Q4.3 (C)
unnamed: J5.1, R6.1
unnamed: J7.1, U3.2
unnamed: J7.2, U3.1
unnamed: J8.1, U4.2
unnamed: J8.2, U4.1
unnamed: J9.1, U5.2
unnamed: J9.2, U5.1
unnamed: J10.1, U6.2
unnamed: J10.2, U6.1
unnamed: Q1.2 (B), R1.1
unnamed: Q2.2 (B), R2.1
unnamed: Q3.2 (B), R3.1
unnamed: Q4.2 (B), R4.1
unnamed: R5.2, U1.17 (~RESET)
unnamed: U1.1 (TXCAN), U2.1 (TXD)
unnamed: U1.2 (RXCAN), U2.4 (RXD)
SCK: J11.5, J12.23, U1.13 (SCK)
SCL: J12.8, J14.4
SDA: J12.10, J14.3
SI: J11.4, J12.19, U1.14 (SI)
SO: J11.3, J12.21, U1.15 (SO)

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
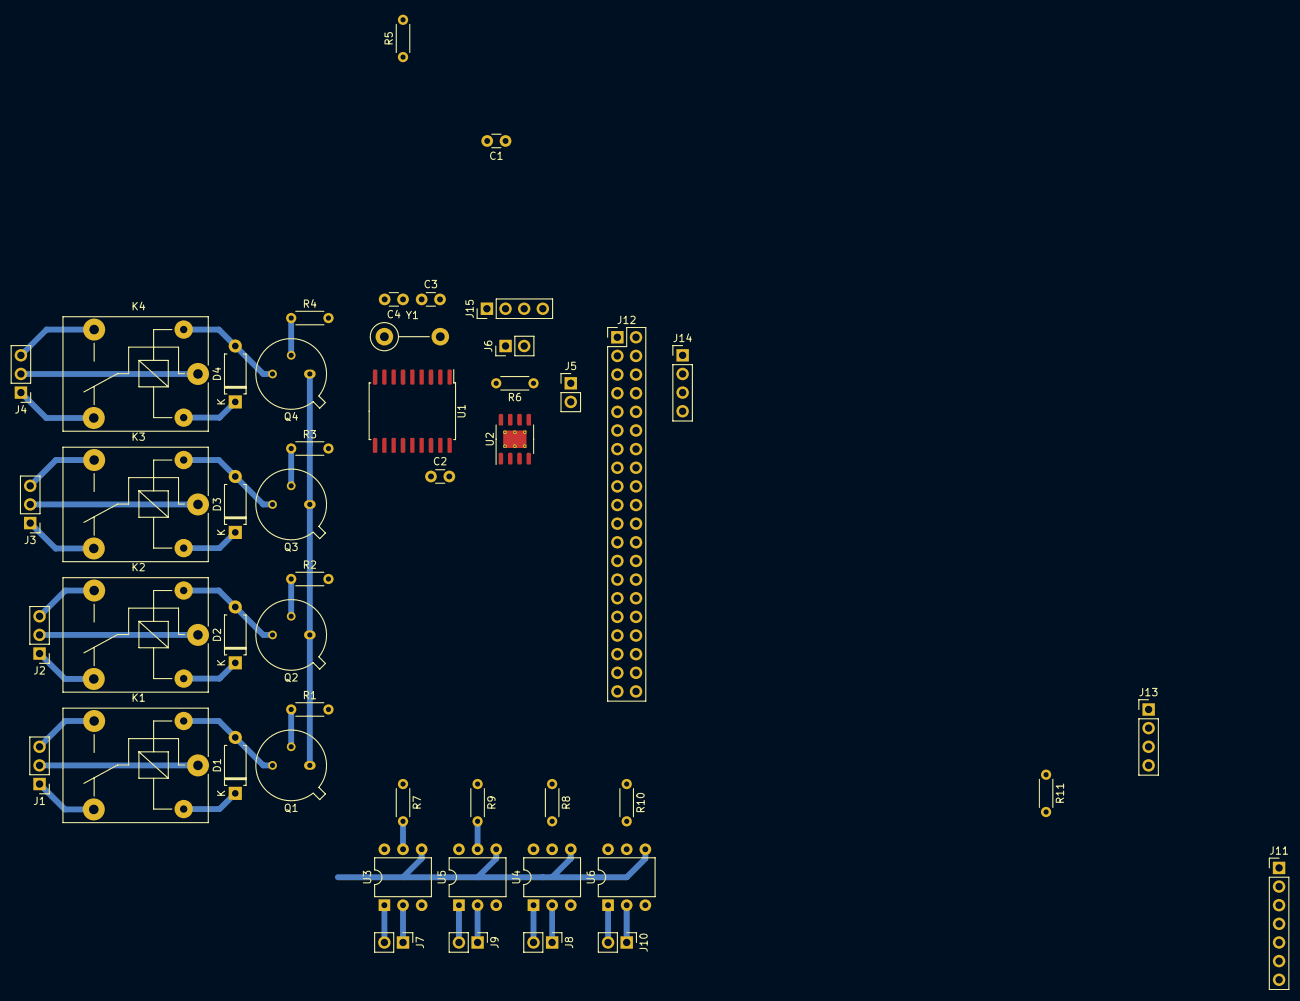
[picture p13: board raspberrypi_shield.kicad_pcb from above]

Board: 2 copper layers, 49 parts (0 on the bottom side), 52 nets.

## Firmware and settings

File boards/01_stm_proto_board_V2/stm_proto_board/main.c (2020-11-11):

/******************** (C) COPYRIGHT 2007 STMicroelectronics ********************
 * File Name          : main.c
 * Author             : MCD Application Team
 * Version            : V1.0
 * Date               : 10/08/2007
 * Description        : Main program body
 ********************************************************************************
 * THE PRESENT SOFTWARE WHICH IS FOR GUIDANCE ONLY AIMS AT PROVIDING CUSTOMERS
 * WITH CODING INFORMATION REGARDING THEIR PRODUCTS IN ORDER FOR THEM TO SAVE TIME.
 * AS A RESULT, STMICROELECTRONICS SHALL NOT BE HELD LIABLE FOR ANY DIRECT,
 * INDIRECT OR CONSEQUENTIAL DAMAGES WITH RESPECT TO ANY CLAIMS ARISING FROM THE
 * CONTENT OF SUCH SOFTWARE AND/OR THE USE MADE BY CUSTOMERS OF THE CODING
 * INFORMATION CONTAINED HEREIN IN CONNECTION WITH THEIR PRODUCTS.
 *******************************************************************************/

/* Includes ------------------------------------------------------------------*/
#include "stm32f10x_lib.h"
#include "stm32f10x_usart.h"
#include "picture.h"
#include "n3310.h"
#include "stm32f10x_can.h"

#include "stm32f10x_rcc.h"
#include "stm32f10x_flash.h"
#include "stm32f10x_gpio.h"
#include "stm32f10x_map.h"
#include "stm32f10x_nvic.h"
#include "stm32f10x_type.h"
#include "stm32f10x_tim.h"

#include "teleinfo.h"
#include "Task.h"
#include "Task_cfg.h"
#include "Fifo_Cfg.h"
#include "Light.h"
#include "serial.h"
#include "LcdMenu.h"

/* Private typedef -----------------------------------------------------------*/
/* Private define ------------------------------------------------------------*/
#define CAN_RX_PIN        GPIO_Pin_11
#define CAN_TX_PIN        GPIO_Pin_12
#define CAN_RS_PIN        GPIO_Pin_5
//#define CAN_GPIO_PORT     GPIOB


#define CAN_BAUDRATE_10KBPS     10
#define CAN_BAUDRATE_20KBPS     20
#define CAN_BAUDRATE_50KBPS     50
#define CAN_BAUDRATE_100KBPS    100
#define CAN_BAUDRATE_125KBPS    125
#define CAN_BAUDRATE_250KBPS    250
#define CAN_BAUDRATE_500KBPS    500
#define CAN_BAUDRATE_1MPBS      1000

#define CAN_BAUDRATE CAN_BAUDRATE_125KBPS

#define PERIOD 1000
/* Private macro -------------------------------------------------------------*/
/* Private variables ---------------------------------------------------------*/
GPIO_InitTypeDef GPIO_InitStructure;
ErrorStatus HSEStartUpStatus;

CAN_FilterInitTypeDef CAN_FilterInitStructure;

int TIM_Pulse_R = 0;
int TIM_Pulse_G = 0;
int TIM_Pulse_B = 0;

/* Private function prototypes -----------------------------------------------*/
void TimerInit(void);
void GPIOInit(void);
void SerialInit(void);
//void SpiInit(void);
void I2C1Init(void);
void CanInit(void);
//void CAN_Config(void);
void ITInit(void);
void Teleinfo_LcdDisplay(void);
void PWMInit(void);
void RCC_Configuration(void);
void NVIC_Configuration(void);
void Delay(vu32 nCount);
void assert_failed(u8* file, u32 line);


//void CAN_Config(void);

/* Private functions ---------------------------------------------------------*/

CanTxMsg CanTxMessage;

/*******************************************************************************
 * Function Name  : main
 * Description    : Main program.
 * Input          : None
 * Output         : None
 * Return         : None
 *******************************************************************************/
int main(void)
{
#ifdef DEBUG
    debug();
#endif
//    u16 R.cvData=0;
    CanTxMsg TxMessage;

    /* SYSTEM DRIVER INIT */
    /* Configure the system clocks */
    RCC_Configuration();
    RCC_APB2PeriphClockCmd(RCC_APB2Periph_AFIO, ENABLE);

    /* NVIC Configuration */
    NVIC_Configuration();

    /* Gpio */
    GPIOInit();
    GPIO_PinRemapConfig(GPIO_Remap_SWJ_JTAGDisable, ENABLE);

    /* COM DRIVER INIT */
    /* Serial Port */
    SerialInit();

    /* SPI init */
    //SpiInit();

    /* I2C1Init() */

    /* CAN Bus */
    CanInit();

    /* Timer */
    TimerInit();

    /* Interrupt */
    ITInit();

    /* PWM */
    PWMInit();

    Light_Init();

    /* CONFIG INIT */

    GPIO_ResetBits(GPIOB, CAN_RS_PIN);

    TxMessage.StdId = 0x444;
    TxMessage.IDE = CAN_ID_STD;
    TxMessage.RTR = CAN_RTR_DATA;
    TxMessage.DLC = 1;
    TxMessage.Data[0] = 0xAA;
    CAN_Transmit(&TxMessage);


    /* MODULE INIT */

    /* Teleinfo initialization */
    teleinfo_Init();
    USART_ITConfig(USART3, USART_IT_RXNE, ENABLE);

    /* FIFO table initialization */
    FIFO_Init(FIFO_table);

    /* LCD Initialization */
    LcdInit();
    LcdClear();

    LcdMenu_Init();
    LcdMenu_Display();

    // Send "START" message on the serial bus
    serial_SendMessage("START\n", 6);

    while(1)
    {
        TaskManager();
    }
}

/*******************************************************************************
 * Function Name  : TimerInit
 * Description    : Initializes Timers.
 * Input          : None
 * Output         : None
 * Return         : None
 *******************************************************************************/
void TimerInit(void)
{
    TIM_TimeBaseInitTypeDef TIMER_InitStructure;

    /* Timer 4 */
    RCC_APB1PeriphClockCmd(RCC_APB1Periph_TIM4, ENABLE); // Enable clock peripheral TIM4

    TIM_TimeBaseStructInit(&TIMER_InitStructure);
    TIMER_InitStructure.TIM_CounterMode = TIM_CounterMode_Up;
    TIMER_InitStructure.TIM_Prescaler = 7200;
    TIMER_InitStructure.TIM_Period = 50;       //5ms delay / 1sec delay: F=72000000/7200/10000 = 1sec
    TIM_TimeBaseInit(TIM4, &TIMER_InitStructure);
    TIM_ITConfig(TIM4, TIM_IT_Update, ENABLE);
    TIM_Cmd(TIM4, ENABLE);
}

void GPIOInit(void)
{
    /* Enable GPIOC clock */
    RCC_APB2PeriphClockCmd(RCC_APB2Periph_GPIOA, ENABLE);
    RCC_APB2PeriphClockCmd(RCC_APB2Periph_GPIOB, ENABLE);
    RCC_APB2PeriphClockCmd(RCC_APB2Periph_GPIOC, ENABLE);


    /* Configure PB.0 as Alternate Function push-pull - TIM3_CH3*/
    GPIO_InitStructure.GPIO_Pin = GPIO_Pin_0;
    GPIO_InitStructure.GPIO_Speed = GPIO_Speed_2MHz;
    GPIO_InitStructure.GPIO_Mode = GPIO_Mode_AF_PP;
    GPIO_Init(GPIOB, &GPIO_InitStructure);

    /* Configure PA.6 as Alternate Function push-pull - TIM3_CH1*/
    GPIO_InitStructure.GPIO_Pin = GPIO_Pin_6;
    GPIO_InitStructure.GPIO_Speed = GPIO_Speed_2MHz;
    GPIO_InitStructure.GPIO_Mode = GPIO_Mode_AF_PP;
    GPIO_Init(GPIOA, &GPIO_InitStructure);

    /* Configure PA.7 as Alternate Function push-pull -  TIM3_CH2*/
    GPIO_InitStructure.GPIO_Pin = GPIO_Pin_7;
    GPIO_InitStructure.GPIO_Speed = GPIO_Speed_2MHz;
    GPIO_InitStructure.GPIO_Mode = GPIO_Mode_AF_PP;
    GPIO_Init(GPIOA, &GPIO_InitStructure);

    /* Configure PC.13 as Output push-pull */
    GPIO_InitStructure.GPIO_Pin = GPIO_Pin_13;
    GPIO_InitStructure.GPIO_Speed = GPIO_Speed_2MHz;
    GPIO_InitStructure.GPIO_Mode = GPIO_Mode_Out_PP;
    GPIO_Init(GPIOC, &GPIO_InitStructure);


    /* USART1 TX */
    /* Configure PB.6 as Alternate Function Push-Pull Output - Serial TX */
    GPIO_InitStructure.GPIO_Pin = GPIO_Pin_6;
    GPIO_InitStructure.GPIO_Speed = GPIO_Speed_10MHz;
    GPIO_InitStructure.GPIO_Mode = GPIO_Mode_AF_PP;
    GPIO_Init(GPIOB, &GPIO_InitStructure);

    /* USART1 RX */
    /* Configure PB.7 as Alternate Function Floating Input - Serial RX */
    GPIO_InitStructure.GPIO_Pin = GPIO_Pin_7;
    GPIO_InitStructure.GPIO_Speed = GPIO_Speed_2MHz;
    GPIO_InitStructure.GPIO_Mode = GPIO_Mode_IN_FLOATING;
    GPIO_Init(GPIOB, &GPIO_InitStructure);

    /* USART2 TX */
    /* Configure PA.2 as Alternate Function Push-Pull Output - Serial TX */
    GPIO_InitStructure.GPIO_Pin = GPIO_Pin_2;
    GPIO_InitStructure.GPIO_Speed = GPIO_Speed_10MHz;
    GPIO_InitStructure.GPIO_Mode = GPIO_Mode_AF_PP;
    GPIO_Init(GPIOA, &GPIO_InitStructure);

    /* USART2 RX */
    /* Configure PA.3 as Alternate Function Floating Input - Serial RX */
    GPIO_InitStructure.GPIO_Pin = GPIO_Pin_3;
    GPIO_InitStructure.GPIO_Speed = GPIO_Speed_2MHz;
    GPIO_InitStructure.GPIO_Mode = GPIO_Mode_IN_FLOATING;
    GPIO_Init(GPIOA, &GPIO_InitStructure);

    /* USART3 TX */
    /* Configure PB.10 as Alternate Function Push-Pull Output - Serial TX */
    GPIO_InitStructure.GPIO_Pin = GPIO_Pin_10;
    GPIO_InitStructure.GPIO_Speed = GPIO_Speed_10MHz;
    GPIO_InitStructure.GPIO_Mode = GPIO_Mode_AF_PP;
    GPIO_Init(GPIOB, &GPIO_InitStructure);

    /* USART3 RX */
    /* Configure PB.11 as Alternate Function Floating Input - Serial RX */
    GPIO_InitStructure.GPIO_Pin = GPIO_Pin_11;
    GPIO_InitStructure.GPIO_Speed = GPIO_Speed_2MHz;
    GPIO_InitStructure.GPIO_Mode = GPIO_Mode_IN_FLOATING;
    GPIO_Init(GPIOB, &GPIO_InitStructure);

    /* CAN1 TX */
    /* Configure PA.12 as Alternate Function Push-Pull Output - CAN TX */
    GPIO_InitStructure.GPIO_Pin = GPIO_Pin_12;  //CAN_TX_PIN
    GPIO_InitStructure.GPIO_Speed = GPIO_Speed_50MHz; //GPIO_Speed_10MHz;
    GPIO_InitStructure.GPIO_Mode = GPIO_Mode_AF_PP;
    GPIO_Init(GPIOA, &GPIO_InitStructure);

    /* CAN RX */
    /* Configure PA.11 as Alternate Function Floating Input - CAN RX */
    GPIO_InitStructure.GPIO_Pin = GPIO_Pin_11;  //CAN_RX_PIN
    GPIO_InitStructure.GPIO_Speed = GPIO_Speed_2MHz;
    GPIO_InitStructure.GPIO_Mode = GPIO_Mode_IN_FLOATING; //GPIO_Mode_IPU; //GPIO_Mode_IN_FLOATING;
    GPIO_Init(GPIOA, &GPIO_InitStructure);

    /* CAN RS */
    /* Configure PB.5 as Push-Pull Output */
    GPIO_InitStructure.GPIO_Pin = GPIO_Pin_5;
    GPIO_InitStructure.GPIO_Speed = GPIO_Speed_10MHz;
    GPIO_InitStructure.GPIO_Mode = GPIO_Mode_Out_PP;
    GPIO_Init(GPIOB, &GPIO_InitStructure);


    /* IO */

    /* Configure PA.0 as Input - PushButton UP */
    GPIO_InitStructure.GPIO_Pin = GPIO_Pin_0;
    GPIO_InitStructure.GPIO_Speed = GPIO_Speed_2MHz;
    GPIO_InitStructure.GPIO_Mode = GPIO_Mode_IPD;
    GPIO_Init(GPIOA, &GPIO_InitStructure);

    /* Configure PA.1 as Input - PushButton RIGHT */
    GPIO_InitStructure.GPIO_Pin = GPIO_Pin_1;
    GPIO_InitStructure.GPIO_Speed = GPIO_Speed_2MHz;
    GPIO_InitStructure.GPIO_Mode = GPIO_Mode_IPD;
    GPIO_Init(GPIOA, &GPIO_InitStructure);

    /* Configure PC.14 as Input - PushButton DOWN */
    GPIO_InitStructure.GPIO_Pin = GPIO_Pin_14;
    GPIO_InitStructure.GPIO_Speed = GPIO_Speed_2MHz;
    GPIO_InitStructure.GPIO_Mode = GPIO_Mode_IPD;
    GPIO_Init(GPIOC, &GPIO_InitStructure);

    /* Configure PC.15 as Input - PushButton LEFT */
    GPIO_InitStructure.GPIO_Pin = GPIO_Pin_15;
    GPIO_InitStructure.GPIO_Speed = GPIO_Speed_2MHz;
    GPIO_InitStructure.GPIO_Mode = GPIO_Mode_IPD;
    GPIO_Init(GPIOC, &GPIO_InitStructure);

    /* Configure PA.4 as Output - PushButton Relay1 */
    GPIO_InitStructure.GPIO_Pin = GPIO_Pin_4;
    GPIO_InitStructure.GPIO_Speed = GPIO_Speed_10MHz;
    GPIO_InitStructure.GPIO_Mode = GPIO_Mode_Out_PP;
    GPIO_Init(GPIOA, &GPIO_InitStructure);

    /* Configure PA.5 as Output - PushButton Relay2 */
    GPIO_InitStructure.GPIO_Pin = GPIO_Pin_5;
    GPIO_InitStructure.GPIO_Speed = GPIO_Speed_10MHz;
    GPIO_InitStructure.GPIO_Mode = GPIO_Mode_Out_PP;
    GPIO_Init(GPIOA, &GPIO_InitStructure);
}


/*******************************************************************************
 * Function Name  : SerialInit
 * Description    : Initializes the serial link.
 * Input          : None
 * Output         : None
 * Return         : None
 *******************************************************************************/
void SerialInit(void)
{
    USART_InitTypeDef USART_InitStruct;

    /* *** USART1 *** */
    /* Enable USART1 clock */
    RCC_APB1PeriphClockCmd(RCC_APB2Periph_USART1, DISABLE);

    /* Enable USART  */
    USART_StructInit(&USART_InitStruct);
    USART_Cmd(USART1, DISABLE);
    USART_Init(USART1, &USART_InitStruct);

    /* Enable IT on USART handler */
    USART_ITConfig(USART1, USART_IT_RXNE, DISABLE);
    USART_ITConfig(USART1, USART_IT_TXE, DISABLE);
    USART_ITConfig(USART1, USART_IT_TC, DISABLE);


    /* *** USART2 *** */
    /* Enable USART2 clock */
    RCC_APB1PeriphClockCmd(RCC_APB1Periph_USART2, ENABLE);

    /* Enable USART  */
    USART_StructInit(&USART_InitStruct);
    USART_Cmd(USART2, ENABLE);
    USART_Init(USART2, &USART_InitStruct);

    /* Enable IT on USART handler */
    USART_ITConfig(USART2, USART_IT_TXE, DISABLE);
    USART_ITConfig(USART2, USART_IT_TC, ENABLE);
    USART_ITConfig(USART2, USART_IT_RXNE, ENABLE);


    /* *** USART3 *** */
    /* Enable USART3 clock */
    RCC_APB1PeriphClockCmd(RCC_APB1Periph_USART3, ENABLE);

    /* Configure UART for EDF Teleinfo */
    USART_InitStruct.USART_BaudRate     = 0x04B0; /* 1200 Baud */
    USART_InitStruct.USART_WordLength   = USART_WordLength_8b;
    USART_InitStruct.USART_StopBits     = USART_StopBits_1;
    USART_InitStruct.USART_Parity       = USART_Parity_Even;
    USART_InitStruct.USART_HardwareFlowControl = USART_HardwareFlowControl_None;
    USART_InitStruct.USART_Mode         = USART_Mode_Rx;    /* Only Rx pin is configured */
    USART_InitStruct.USART_Clock        = USART_Clock_Disable;
    USART_InitStruct.USART_CPOL         = USART_CPOL_Low;
    USART_InitStruct.USART_CPHA         = USART_CPHA_1Edge;
    USART_InitStruct.USART_LastBit      = USART_LastBit_Disable;

    /* Enable USART  */
    USART_Cmd(USART3, ENABLE);
    USART_Init(USART3, &USART_InitStruct);

    /* Enable IT on USART handler */
    USART_ITConfig(USART3, USART_IT_RXNE, DISABLE);
    USART_ITConfig(USART3, USART_IT_TXE, DISABLE);
    USART_ITConfig(USART3, USART_IT_TC, DISABLE);
}


/*******************************************************************************
 * Function Name  : SpiInit
 * Description    : Initializes the SPI link.
 * Input          : None
 * Output         : None
 * Return         : None
 *******************************************************************************/
//void SpiInit(void)
//{
//    SPI_InitTypeDef SPI_InitStruct;
//
//    /* *** SPI1 *** */
//    /* Enable SPI1 clock */
//    RCC_APB1PeriphClockCmd(RCC_APB2Periph_SPI1, ENABLE);
//
////    PORT.GPIO_Mode  = GPIO_Mode_AF_PP;
////    PORT.GPIO_Speed = GPIO_Speed_50MHz;
////    PORT.GPIO_Pin   = GPIO_Pin_13 | GPIO_Pin_14 | GPIO_Pin_15;
////    GPIO_Init(GPIOB, &PORT);
//
//    /* Initialize SPI1 with default parameter*/
//    SPI_Init(SPI1, SPI_InitStruct);
//
//    /* Configure SPI1 for nRF24L01 */
//    SPI_InitStruct.SPI_Mode = SPI_Mode_Master;
//    SPI_InitStruct.SPI_BaudRatePrescaler = SPI_BaudRatePrescaler_2;
//    SPI_InitStruct.SPI_Direction = SPI_Direction_2Lines_FullDuplex;
//    SPI_InitStruct.SPI_CPOL = SPI_CPOL_Low;
//    SPI_InitStruct.SPI_CPHA = SPI_CPHA_1Edge;
//    SPI_InitStruct.SPI_CRCPolynomial = 7;
//    SPI_InitStruct.SPI_DataSize = SPI_DataSize_8b;
//    SPI_InitStruct.SPI_FirstBit = SPI_FirstBit_MSB;
//	SPI_InitStruct.SPI_NSS = SPI_NSS_Soft;
//
//    /* Enable SPI1 */
//	SPI_Init(SPI1, &SPI_InitStruct);
//	SPI_NSSInternalSoftwareConfig(SPI1, SPI_NSSInternalSoft_Set);
//    SPI_Cmd(SPI1, ENABLE);
//
//    /* Enable IT on SPI1 handler */
//    USART_ITConfig(SPI1, SPI_IT_RXNE, DISABLE);
//    USART_ITConfig(SPI1, SPI_IT_TXE, DISABLE);
//    USART_ITConfig(SPI1, SPI_IT_ERR, DISABLE);
//
//
//
//    /* *** SPI2 *** */
//    /* Enable SPI2 clock */
//	RCC_APB1PeriphClockCmd(RCC_APB1Periph_SPI2, DISABLE);
//
//    /* Initialize SPI2 with default parameter*/
////    SPI_Init(SPI2, SPI_InitStruct);
//
//    /* Configure SPI2 */
//    SPI_InitStruct.SPI_Mode = SPI_Mode_Master;
//    SPI_InitStruct.SPI_BaudRatePrescaler = SPI_BaudRatePrescaler_2;
//    SPI_InitStruct.SPI_Direction = SPI_Direction_2Lines_FullDuplex;
//    SPI_InitStruct.SPI_CPOL = SPI_CPOL_Low;
//    SPI_InitStruct.SPI_CPHA = SPI_CPHA_1Edge;
//    SPI_InitStruct.SPI_CRCPolynomial = 7;
//    SPI_InitStruct.SPI_DataSize = SPI_DataSize_8b;
//    SPI_InitStruct.SPI_FirstBit = SPI_FirstBit_MSB;
//    SPI_InitStruct.SPI_NSS = SPI_NSS_Soft;
//
//    /* Enable SPI2 */
//   	USART_Init(SPI2, &SPI_InitStruct);
//   	SPI_NSSInternalSoftwareConfig(SPI2, SPI_NSSInternalSoft_Set);
//	SPI_Cmd(SPI2, DISABLE);
//
//    /* Enable IT on SPI2 handler */
//    USART_ITConfig(SPI2, SPI_IT_RXNE, DISABLE);
//    USART_ITConfig(SPI2, SPI_IT_TXE, DISABLE);
//    USART_ITConfig(SPI2, SPI_IT_ERR, DISABLE);
//
//}


/*******************************************************************************
 * Function Name  : I2C1Init
 * Description    : Initializes the I2C 1 link.
 * Input          : None
 * Output         : None
 * Return         : None
 *******************************************************************************/
void I2C1Init(void)
{
    I2C_InitTypeDef  I2C_InitStructure;
    GPIO_InitTypeDef  GPIO_InitStructure;

    RCC_APB1PeriphClockCmd(RCC_APB1Periph_I2C1, ENABLE);

    /* Configure I2C_EE pins: SCL and SDA */
//  GPIO_InitStructure.GPIO_Pin =  GPIO_Pin_6 | GPIO_Pin_7;
    GPIO_InitStructure.GPIO_Pin =  GPIO_Pin_8 | GPIO_Pin_9;
    GPIO_InitStructure.GPIO_Speed = GPIO_Speed_50MHz;
    GPIO_InitStructure.GPIO_Mode = GPIO_Mode_AF_OD;
    GPIO_Init(GPIOB, &GPIO_InitStructure);

    /* I2C configuration */
    I2C_InitStructure.I2C_Mode = I2C_Mode_I2C;
    I2C_InitStructure.I2C_DutyCycle = I2C_DutyCycle_2;
    I2C_InitStructure.I2C_OwnAddress1 = 0x38;
    I2C_InitStructure.I2C_Ack = I2C_Ack_Enable;
    I2C_InitStructure.I2C_AcknowledgedAddress = I2C_AcknowledgedAddress_7bit;
    I2C_InitStructure.I2C_ClockSpeed = 100000;

    /* I2C Peripheral Enable */
    I2C_Cmd(I2C1, ENABLE);
    /* Apply I2C configuration after enabling it */
    I2C_Init(I2C1, &I2C_InitStructure);

    GPIO_PinRemapConfig(GPIO_Remap_I2C1, ENABLE); //Remap I2C1 to use PB8 and PB9
}


/*******************************************************************************
 * Function Name  : CanInit
 * Description    : Initializes the CAN controller module.
 * Input          : None
 * Output         : None
 * Return         : None
 *******************************************************************************/
void CanInit(void)
{
    CAN_InitTypeDef CAN_InitStruct;

    /* Enable CAN clock */
    RCC_APB1PeriphClockCmd(RCC_APB1Periph_CAN, ENABLE);
    GPIO_PinRemapConfig(GPIO_Remap1_CAN, DISABLE);
    GPIO_PinRemapConfig(GPIO_Remap2_CAN, DISABLE);

    /* Enable USART  */
    CAN_StructInit(&CAN_InitStruct);
//    CAN_Cmd(CAN, ENABLE);
    CAN_Init(&CAN_InitStruct);

    //Configure CAN
    CAN_StructInit(&CAN_InitStruct);

    /* CAN cell init */
    CAN_InitStruct.CAN_TTCM = DISABLE;
    CAN_InitStruct.CAN_ABOM = DISABLE;
    CAN_InitStruct.CAN_AWUM = DISABLE;
    CAN_InitStruct.CAN_NART = DISABLE;
    CAN_InitStruct.CAN_RFLM = DISABLE;
    CAN_InitStruct.CAN_TXFP = DISABLE;
    CAN_InitStruct.CAN_Mode = CAN_Mode_Normal;

//  /* CAN Baudrate = 250kbps */
//  /* not working */
//  CAN_InitStruct.CAN_SJW = CAN_SJW_1tq;
//  CAN_InitStruct.CAN_BS1 = CAN_BS1_3tq;
//  CAN_InitStruct.CAN_BS2 = CAN_BS2_5tq;
//  CAN_InitStruct.CAN_Prescaler = 4;
//
//  /* CAN Baudrate = 500kbps */
    /* not working */
//  CAN_InitStruct.CAN_SJW = CAN_SJW_1tq;
//  CAN_InitStruct.CAN_BS1 = CAN_BS1_5tq;
//  CAN_InitStruct.CAN_BS2 = CAN_BS2_2tq;
//  CAN_InitStruct.CAN_Prescaler = 1;
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

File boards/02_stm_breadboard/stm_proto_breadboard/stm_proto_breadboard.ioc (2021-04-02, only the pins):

Mcu.UserName=STM32F103C8Tx
PB14.GPIO_Label=RELAY3
PD0-OSC_IN.Signal=RCC_OSC_IN
PB13.GPIO_Label=RELAY2
PB13.Signal=GPIO_Output
PB15.Signal=GPIO_Output
PD1-OSC_OUT.Signal=RCC_OSC_OUT
PA13.Signal=SYS_JTMS-SWDIO
PA12.Signal=CAN_TX
PA9.Signal=USART1_TX
PB14.Signal=GPIO_Output
PB12.GPIO_Label=RELAY1
PB15.GPIO_Label=RELAY4
PA2.Signal=USART2_TX
PA11.Signal=CAN_RX
PA14.Signal=SYS_JTCK-SWCLK
PA10.Signal=USART1_RX
PB12.Signal=GPIO_Output
PA3.Signal=USART2_RX

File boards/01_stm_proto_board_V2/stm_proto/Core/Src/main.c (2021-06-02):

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
/* Includes ------------------------------------------------------------------*/
#include "main.h"

/* USER CODE BEGIN Includes */
#include "Task.h"
/* USER CODE END Includes */

CAN_HandleTypeDef hcan;

TIM_HandleTypeDef htim4;

/* USER CODE BEGIN PV */
CAN_TxHeaderTypeDef CanTxHeader;
CAN_RxHeaderTypeDef CanRxHeader;
/* USER CODE END PV */

void SystemClock_Config(void);
static void MX_GPIO_Init(void);
static void MX_CAN_Init(void);
static void MX_TIM4_Init(void);
static void MX_NVIC_Init(void);
/* USER CODE BEGIN PFP */
void CAN_Config(void);
/* USER CODE END PFP */

/* USER CODE BEGIN 0 */

void HAL_TIM_PeriodElapsedCallback(TIM_HandleTypeDef *htim)
{
	if(htim->Instance == TIM4)
	{
	    Task_Manager_IT();
	}
}


void HAL_CAN_RxFifo0FullCallback(CAN_HandleTypeDef *hcan)
{

}

void HAL_CAN_RxFifo0MsgPendingCallback(CAN_HandleTypeDef *hcan)
{
  CAN_RxHeaderTypeDef CanHeader;
  uint8_t CanRxData[8];

  HAL_CAN_GetRxMessage(hcan, CAN_RX_FIFO0, &CanHeader, CanRxData);

  if (CanHeader.IDE == CAN_ID_STD )
  {
      // Traitement des donnéess

	  OrderProcess(CanHeader.StdId, CanRxData, CanHeader.DLC);
  }
}

uint8_t cpt = 0;
/* USER CODE END 0 */

/**
  * @brief  The application entry point.
  * @retval int
  */
int main(void)
{
  /* USER CODE BEGIN 1 */
  unsigned char str_buff[15] ={0};


  CAN_TxHeaderTypeDef canHeader;
  unsigned char canBuff[8]={1, 2, 3, 4, 5, 6, 7, 8};
  unsigned char canMailBox;
  unsigned char * pTxMailbox=&canMailBox;
  /* USER CODE END 1 */

  /* MCU Configuration--------------------------------------------------------*/

  /* Reset of all peripherals, Initializes the Flash interface and the Systick. */
  HAL_Init();

  /* Configure the system clock */
  SystemClock_Config();

  /* Initialize all configured peripherals */
  MX_GPIO_Init();
  MX_CAN_Init();
  MX_TIM4_Init();

  /* Initialize interrupts */
  MX_NVIC_Init();
  /* USER CODE BEGIN 2 */

  /* Configure the CAN Filter */
  {
    CAN_FilterTypeDef  sFilterConfig;
    sFilterConfig.FilterBank = 0;
    sFilterConfig.FilterMode = CAN_FILTERMODE_IDMASK;
    sFilterConfig.FilterScale = CAN_FILTERSCALE_32BIT;
    sFilterConfig.FilterIdHigh = 0x0000;
    sFilterConfig.FilterIdLow = 0x0000;
    sFilterConfig.FilterMaskIdHigh = 0x0000;
    sFilterConfig.FilterMaskIdLow = 0x0000;
    sFilterConfig.FilterFIFOAssignment = CAN_RX_FIFO0;
    sFilterConfig.FilterActivation = ENABLE;
    sFilterConfig.SlaveStartFilterBank = 14;

    if (HAL_CAN_ConfigFilter(&hcan, &sFilterConfig) != HAL_OK)
    {
      /* Filter configuration Error */
      Error_Handler();
    }

    /* Activate CAN RX notification */
    if (HAL_CAN_ActivateNotification(&hcan, CAN_IT_RX_FIFO0_MSG_PENDING) != HAL_OK)
    {
      /* Notification Error */
      Error_Handler();
    }

    /* Configure Transmission process */
    canHeader.StdId = 0x321;
    canHeader.ExtId = 0x01;
    canHeader.RTR = CAN_RTR_DATA;
    canHeader.IDE = CAN_ID_STD;
    canHeader.DLC = 2;
    canHeader.TransmitGlobalTime = DISABLE;

  }
  HAL_TIM_Base_Start_IT(&htim4);

  hcan.Instance->MCR = 0x60; //IMPORTANT FOR DEBUG!!!!!!!
  TaskManager_Init();

  Light_Init();

  //HAL_CAN_WakeUp(&hcan);

  canHeader.StdId = 0x123;
  canHeader.ExtId = 0x21;
  canHeader.IDE = CAN_ID_STD;
  canHeader.RTR = CAN_RTR_DATA;
  canHeader.DLC = 4;
  canHeader.TransmitGlobalTime = DISABLE;

  HAL_CAN_AddTxMessage(&hcan, &canHeader, canBuff, pTxMailbox);


  /* USER CODE END 2 */

  /* Infinite loop */
  /* USER CODE BEGIN WHILE */
  while (1)
  {
    /* USER CODE END WHILE */

    /* USER CODE BEGIN 3 */
    TaskManager();
  }
  /* USER CODE END 3 */
}

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
/* USER CODE BEGIN 4 */
void CAN_Config(void)
{
  CAN_FilterTypeDef  sFilterConfig;

  sFilterConfig.FilterBank = 0;
  sFilterConfig.FilterMode = CAN_FILTERMODE_IDMASK;
  sFilterConfig.FilterScale = CAN_FILTERSCALE_32BIT;
  sFilterConfig.FilterIdHigh = 0x320 << 5;
  sFilterConfig.FilterIdLow = 0;
  sFilterConfig.FilterMaskIdHigh = 0xFFF << 5;
  sFilterConfig.FilterMaskIdLow = 0;
  sFilterConfig.FilterFIFOAssignment = CAN_RX_FIFO0;
  sFilterConfig.FilterActivation = DISABLE;
  sFilterConfig.SlaveStartFilterBank = 14;

  //HAL_CAN_ConfigFilter(&hcan, &sFilterConfig);

  if (HAL_CAN_ConfigFilter(&hcan, &sFilterConfig) != HAL_OK)
   {
   /* Filter configuration Error */
   Error_Handler();
   }

  HAL_CAN_Start(&hcan);

  HAL_CAN_ActivateNotification(&hcan, CAN_IT_RX_FIFO0_MSG_PENDING);
  HAL_CAN_ActivateNotification(&hcan, CAN_IT_RX_FIFO0_FULL);

  HAL_CAN_ActivateNotification(&hcan, CAN_IT_RX_FIFO1_MSG_PENDING);
  HAL_CAN_ActivateNotification(&hcan, CAN_IT_RX_FIFO1_FULL);




  CanTxHeader.StdId = 0x320;
  CanTxHeader.ExtId = 0x01;
  CanTxHeader.RTR = CAN_RTR_DATA;
  CanTxHeader.IDE = CAN_ID_STD;
  CanTxHeader.DLC = 2;
  CanTxHeader.TransmitGlobalTime = DISABLE;
}
/* USER CODE END 4 */
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


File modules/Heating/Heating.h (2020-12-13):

/************************************************************************
 * File Name          : Heating.h
 * Author             : author
 * Date               : 23/02/2020
 * Description        : header file for heating functions
 ***********************************************************************/
#ifndef HEATING_H_
#define HEATING_H_

/************************************************************************
* INCLUDES *
************************************************************************/

/************************************************************************
* DEFINES *
************************************************************************/
#define HEATING_MAX_DEVICES         2
#define DELTA_TEMP_ECO            2*2
#define DELTA_TEMP_CONFORT        2*2

/************************************************************************
* STRUCTURES *
************************************************************************/
typedef enum
{
  HEATING_MODE_OFF = 0,
  HEATING_MODE_NORMAL,
  HEATING_MODE_ECO,
  HEATING_MODE_CONFORT,
  HEATING_MODE_FROST,
//  HEATING_MODE_ERROR,
//  HEATING_MODE_INIT,
  HEATING_MODE_INHIBIT,
  HEATING_MODE_ACTIVATE
}T_Heating_Mode;

typedef enum
{
  HEATING_STATE_OFF,
  HEATING_STATE_WAIT,
  HEATING_STATE_HEAT,
  HEATING_STATE_,
}T_HeatingSM_State;

typedef struct
{
  T_Heating_Mode mode; 
  T_HeatingSM_State state;
  unsigned char consigne;
  unsigned char threshold;
  unsigned char temperature;
  unsigned char temperature_default;
  unsigned char temperature_confort;
}T_HeatingConfig;

/************************************************************************
* GLOBAL VARIABLES *
************************************************************************/
extern T_HeatingConfig HeatingState[HEATING_MAX_DEVICES];

/************************************************************************
* FUNCTIONS PROTOTYPES *
************************************************************************/
void Heating_Init(void);
unsigned char HeatingOrderTmt( unsigned char DeviceId, unsigned char Order, unsigned char *param);
unsigned char Heating_mainfunction(void);

#endif /* HEATING_H_ */

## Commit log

2018-04-09 Implement CAN bus module
2018-08-11 Create schematic + add debug command in makefile
    [pinout.ods, stm_proto_board.kicad_pcb, stm_proto_board.sch]
2018-08-12 Add PWM + template code for other modules
    [pinout.ods, stm_proto_board.sch]
2018-08-12 Add board photos
2018-08-12 prototype photos
2018-09-03 Add 3 PWM channels
2018-09-13 Add PushButton module
    [pinout.ods]
2018-10-28 Add LED strip management
2019-02-09 LedStrip management
    [pinout.ods, stm_proto_board.sch]
2020-02-15 revert stm32f10x_it.c
2020-02-23 Add Heating module + cleanup
2020-06-10 fix warnings and code
    [Light.c, teleinfo.c]
2020-10-16 Create module Heating
2020-10-16 update tests for module Heating
2020-10-16 update test + correct code
    [Heating.h, test_main.c]
2020-10-18 Update PCB proto-board
    [file5B9A0F3F.sch, file5BCA0F9A.sch, stm_proto_board.kicad_pcb]
2020-10-20 PCB design
    [stm_proto_board.kicad_pcb, stm_proto_board.sch]
2020-10-21 update PCB
    [stm_proto_board.kicad_pcb, stm_proto_board.sch]
2020-10-25 add PCB proto board wrapped + raspberry + cables
    [cables.kicad_pcb, cables.sch, file5B9A0F3F.sch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]
2020-10-26 test returns the number of failures
    [test_main.c]
2020-11-07 Update schematic SDA/SDL pins
    [stm_proto_board.kicad_pcb, stm_proto_board.sch]
2020-11-07 Add intercom/door board
    [save_schematics.sch, stm_proto_board.kicad_pcb, stm_proto_board.sch]
2020-11-07 Update schematic
    [cables.sch, raspberrypi_shield.kicad_pcb, raspberrypi_shield.sch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]
2020-11-08 update schematics
    [raspberrypi_shield.sch, stm_intercom_door_entrance.kicad_pcb, stm_intercom_door_entrance.sch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]
2020-11-11 update boards descriptions
2020-12-13 Clean up + improve pin module
2020-12-22 Update PCB proto board
    [stm_proto_board.kicad_pcb, stm_proto_board.sch]
2020-12-22 PCB update
    [stm_intercom_door_entrance.kicad_pcb, stm_proto_board.kicad_pcb]
2020-12-22 change folders structure
    [flash.cfg]
2020-12-22 rename board 01
    [flash.cfg]
2021-02-14 update tests generation
    [cables.sch]
2021-02-26 Add proto breadboard configured zith STM32CubeIde
2021-04-02 separate board config from code ressources
2021-04-02 Add PCB for module 3
    [can_uart_converter.sch, ressources.sch]
2021-06-02 Move current code to subfolder
    [flash.cfg]
2021-06-02 Add new project from STM32CubeIde

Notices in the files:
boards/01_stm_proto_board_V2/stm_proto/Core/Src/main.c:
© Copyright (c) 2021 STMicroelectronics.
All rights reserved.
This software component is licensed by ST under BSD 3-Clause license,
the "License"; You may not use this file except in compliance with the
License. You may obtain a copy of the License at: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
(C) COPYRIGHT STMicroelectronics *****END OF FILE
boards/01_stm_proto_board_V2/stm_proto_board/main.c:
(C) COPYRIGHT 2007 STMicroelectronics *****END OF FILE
